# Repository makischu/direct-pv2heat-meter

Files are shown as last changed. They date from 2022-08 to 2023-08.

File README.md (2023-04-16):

# direct-pv2heat-meter

## the (initial) idea

This project is about an experimental power2heat application. Photovoltaic shall be used to heat water with a resistive heating rod. Directly off-grid, without any inverter, MPPT tracker, or the like. Note that this is known to be a dumb solution in terms of efficiency (e.g. see [1] or [2]). My goal with this project is to collect data to see how bad my solution really is. And another goal is to keep it safe.

**DANGER!** This project deals with dangerous electric power. Do not reproduce except you really know what you are doing!

As there is no regulator involved to match the characteristic of the pv panels and the heater, special care was taken to dimensioning of the parts. At the start of the project I was about to buy a hot-water heat pump, which comes with a heating rod of 1.5kW@230V (equivalents 6,52A or 35,3 Ohm). This one is not required for the intended usage, so I will use it for the project to avoid any extra plumber work. My local photovoltaic dealer offered 375W modules (datasheet names Vmpp=34,6/32,3V and Impp=10,8/8,7A which equivalents Rmpp=3,2/3,7Ohm per module).

[3] proposes a "PV magic water heater formula: Element ohms equal (Vmp/Imp) x 1.40", which translates to a recommondation of 6.8 pv modules in my case. I chose 6. 6 es even, so I can build 2 strings of 3 modules for an alternate usage. Kirchhoff allows us to double the current by simply putting 2 strings in parallel, and power goes with current squared, so I did not want to waste that option too early.

Dividing into 2 strings resulted in another advantage. The maximum input voltage reduced to 3 *41,1V *1,1=135V. This lead me to the idea of using a TL783 as a first stage of my logic power supply, as it allows 125V in-out voltage difference. Unforfunately it was not availabe at the time of ordering and I did not find a 1:1 replacement. I still wanted to power the logic by the pv itself and ensure galvanic isolation, so i designed in an extra intermediate tap in one string. So the maximum input voltage the logic has to deal with is 41,1V *1,1=45V. This is low enough to find an (available) linear regulator for 24V (for relais supply) and a DC DC converter with 3.3V output (for the logic). Furthermore this allows for direct connection to the current metering IC's breakout board SparkX Power Meter - ACS37800 (Qwiic) [4] (<60V). (not a genius idea; see drawbacks below).

See image for the first attempt's overall wiring:

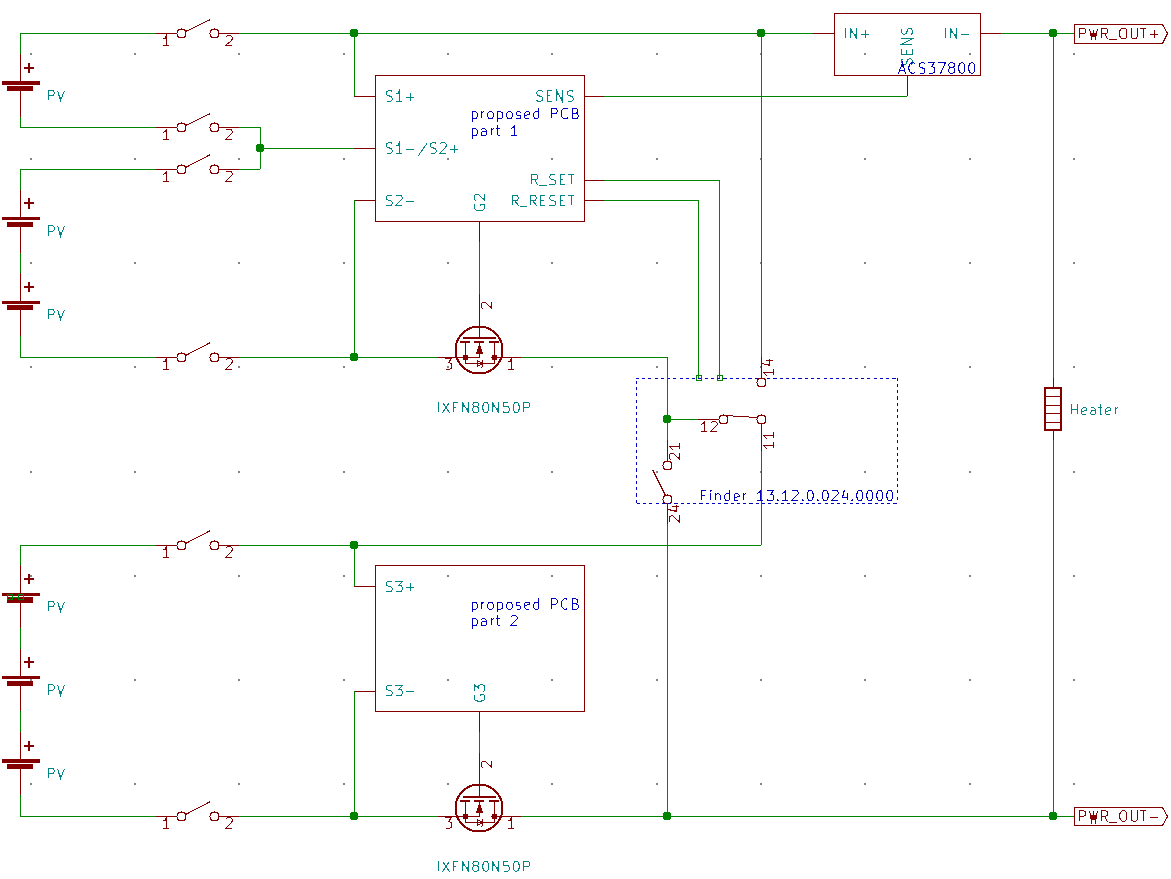
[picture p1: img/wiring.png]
Wiring


I said I want to keep the usage safe. This includes that power to the heater shall be interruptable. A certain temperature shall not be exceeded. The interruption is realized with FETs. Big ones with screw terminals (for the beginning I did not want to deal with high power on the PCB). As a temperature sensor I want to use the built-on from the hot-water heat pump. The control is not realized yet, but for the pv hardware I realized it as following: A on-command/trigger-signal has to be received every few seconds. If not, the power output will shut down. That should be safe enough for me.

The logic is realized on an ESP32, as it is well-affordable and offers BLE (read: established way of low-power galvanically isolated communication). As counterpart I built a BLE-Wifi-Bridge, also based on an ESP32 (I chose a Firebeetle, so no soldering on this part). That was enough that all the rest (logging, controlling) could be realized in software.

Although it did not work well, I leave the initially planned (and built) system overview here for reference:

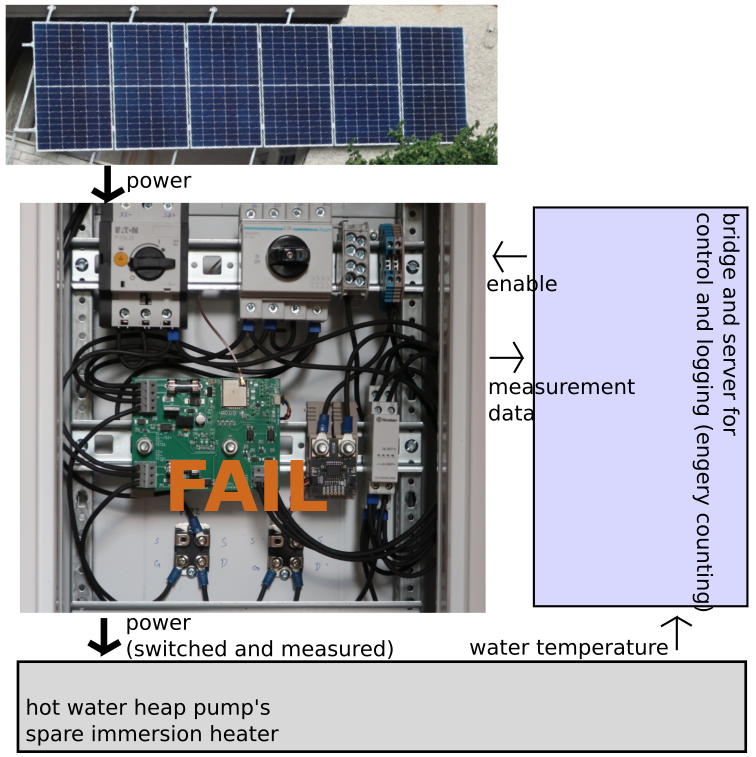
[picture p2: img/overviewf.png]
Overview


<BR/><BR/><BR/>

## the evolution

This chapter is about selected aspects of the (ongoing) development.

### Delivery Issues

Unforfunately the hot water heat pump was not delivered in time (and still isn't at the time of writing. a typical 2022 issue). So I changed the scope of heating: from water to air. Thus I avoid the delivery issue as I have a few dumb (=resisitve) 230V heaters lying around. As they have different wattages a new idea came across: Can I use different permutations to optimize efficiency? Later. First, I have to solve a different problem:

### Logic Supply Issues. Or 3 $\neq$ 1+2. Or: About pv panel mismatch.

The circuit generally works. But under certain conditions I could not turn on the load without the microcontroller going in reset, which turns the load off again by design. It turns out that the logic's supply voltage :purple_square: drops. Why? 

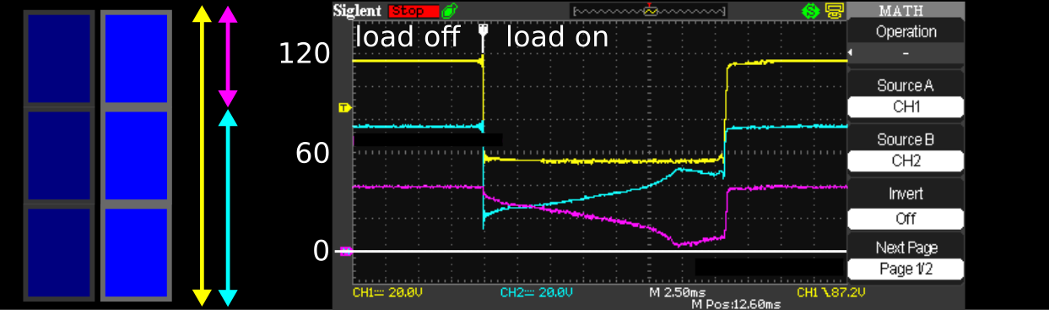
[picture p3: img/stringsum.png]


When connecting a load under low light conditions, the string voltage :yellow_square: drops, in this case from ~120 to ~60V. Then it remains stable. That is expected and should *not* cause any issues.

But I made a wrong assumption. I assumed that every panel contributes the same voltage to the string, like batteries. This is what I tried to exploit to ease my logic supply. But as I could see on the scope, the panel's voltages can diverge a lot! Almost down to zero for the panel that is supposed to support the microcontroller.

The source of this effect is mismatch. See [5] for a good introduction to the topic. In addition to inherent panel variation, we draw an extra current from one panel (to supply the logic). This current is only ~30mA (@20V). This sounds negligable in contrast to the load current (in general >1A). But it is not. Why?

Because a pv panel is not (always) a voltage source. It is known to be more like a current source. Well in my opinion it is both, but it depends on the operating point. And for operation points "far left of the MPP" a current source is definitely the better model. See plot.

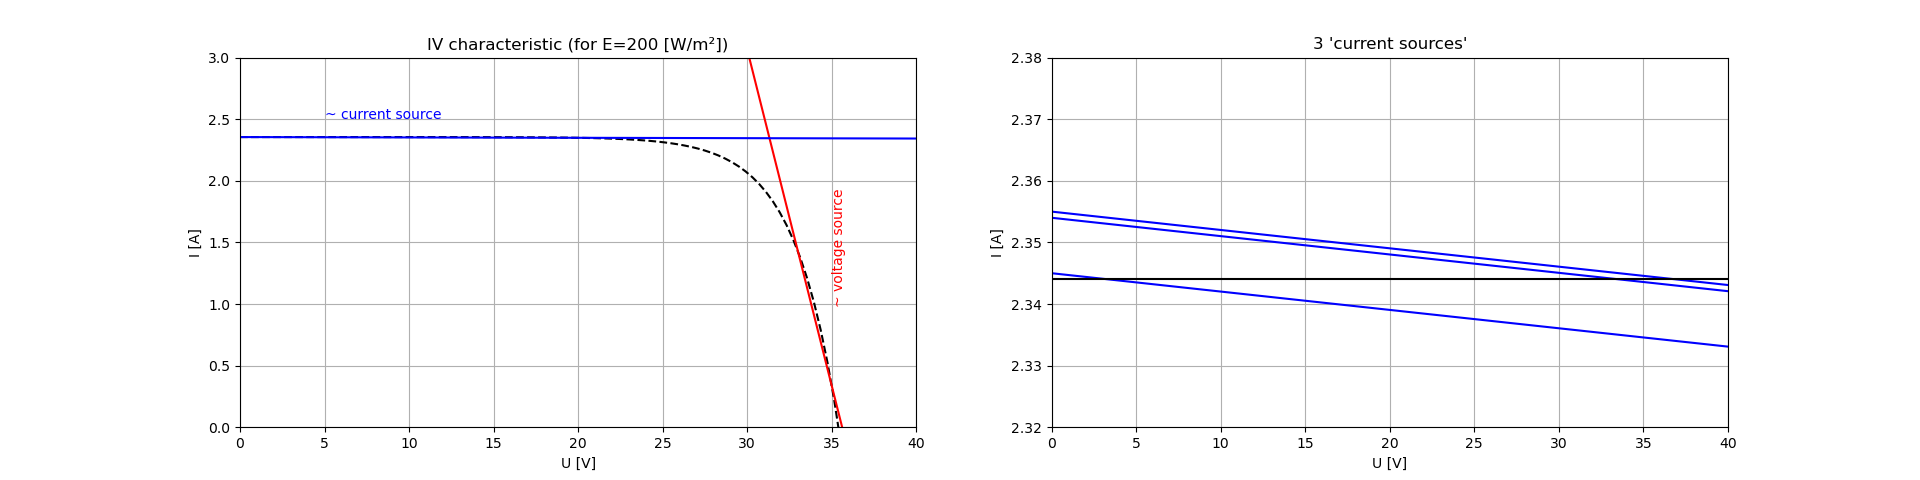
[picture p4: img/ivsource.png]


Let's zoom in to our "current source", plot it for 3 panels, assuming a little variation. As Kirchoff forces the current to be the same for all 3, voltage has to vary *a lot*. 

In the end this effect makes the initially proposed circuit fail in "current source mode", or said otherwise: it only works for high irradiation. 

A possible solution: Characterize the panels, hope that one is significantly better than all others, and hand-select the "best" one for the logic supply. Or make all others worse artifically, by a small extra load. Both approaches do not seem reasonable to me.

A more realistic solution: Generate the required votages from the whole string (3 panels instead of just 1). Unfortunately it is not soo easy to find (linear) regulators or (dc/dc) converters for that (wide) input range. Furthermore we need to consider the similar effect when switching from parallel (2x3 panels) to serial (1x6 panels) configuration. 

### Burnt FET and relay

Although overengineered in terms of voltage and current ability I managed to burn FETs. After some experimentes it was conductive regardless of gate signal. Consequently I burnt the relay, too, as it is not designed to break significant DC current at high voltage. For our purpose FETs shall either block or conduct, nothing in between, to prevent excessive power loss and thus cause its death. I assume I did not care enough about that in my first design.

So I went for a gate driver IC. Most of them offer undervoltage lockout (UVLO), but all that i have seen would suffer from oscillation in my application. UVLO disables the FET when voltage is low, thus removing the load. Removing the load leads to increasing voltage, thus enabling the FET again. For this reason I introduced a latching logic, which causes the FET to remain off in case of UVLO. 

### Server Logic

While I started with almost every logic implemented at a server in (python) software, the external components should not be stricly necessary in the long term. More work shall be done in firmware. 

[Here](theory/datasheettheory.md) I described some theory that might help with devoloping the optimization algorithm.

<BR/><BR/><BR/>

## the (preliminary) final solution

There were further issues I addressed with intermediate experiments (it's not a full diary here). In the end this resulted in a new architecture (where 1 power transistor and 1 relay is sufficient) and several small improvements (robust multi-stage power supply generation for the logic, strong fet driver with latching UVLO, also powerpath integrated on a PCB, thus avoiding external wiring, including voltage+current measurement, reducing external components, ...). 

The new architecture's power path:

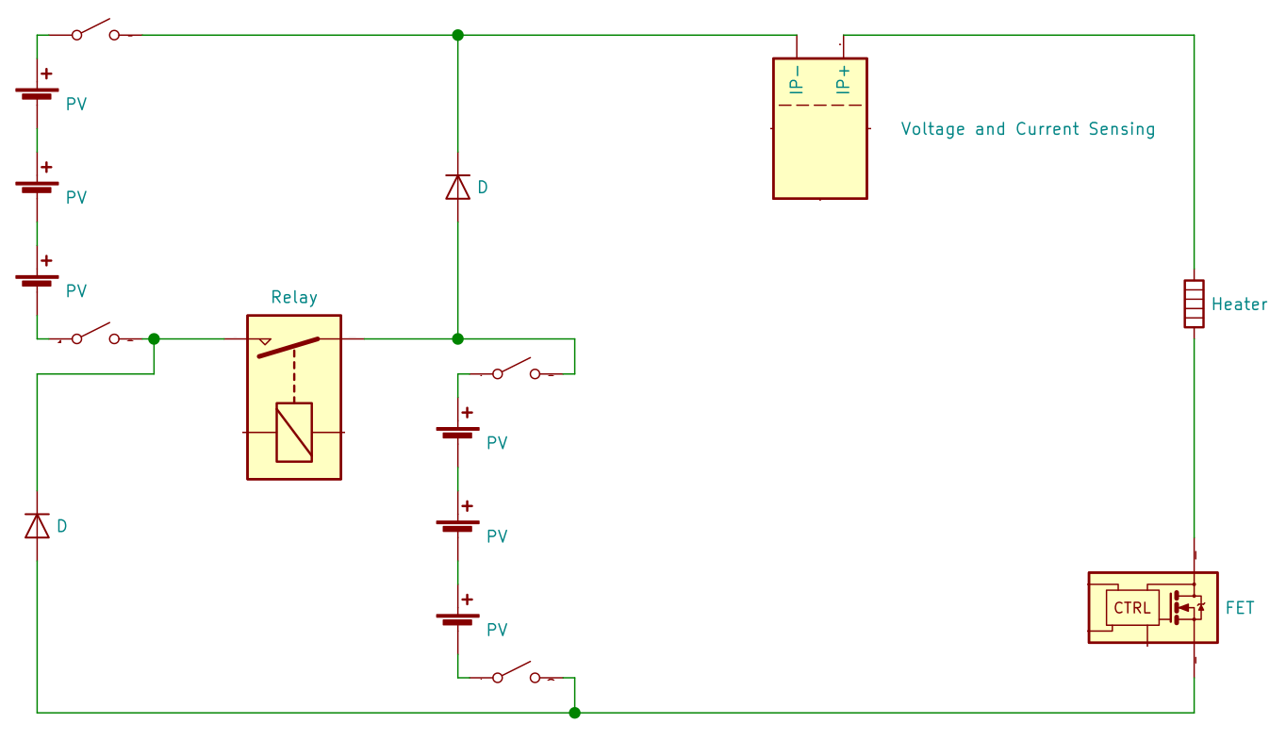
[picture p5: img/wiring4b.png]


Updated system overview:

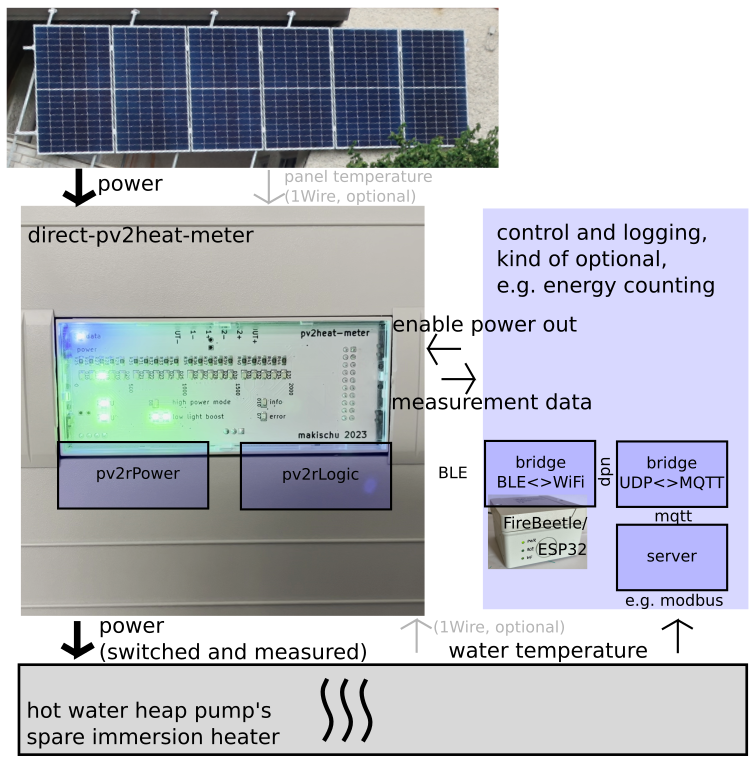
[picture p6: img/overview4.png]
Overview


Although schematics and source code are available in this repository, there is no full bill of material or building instruction. Note that the main unit consists of 2 dependent PCBs. This enabled sequential development and stacking in a din rail housing (an apra rail DB 6).  Here is an impression of the result:

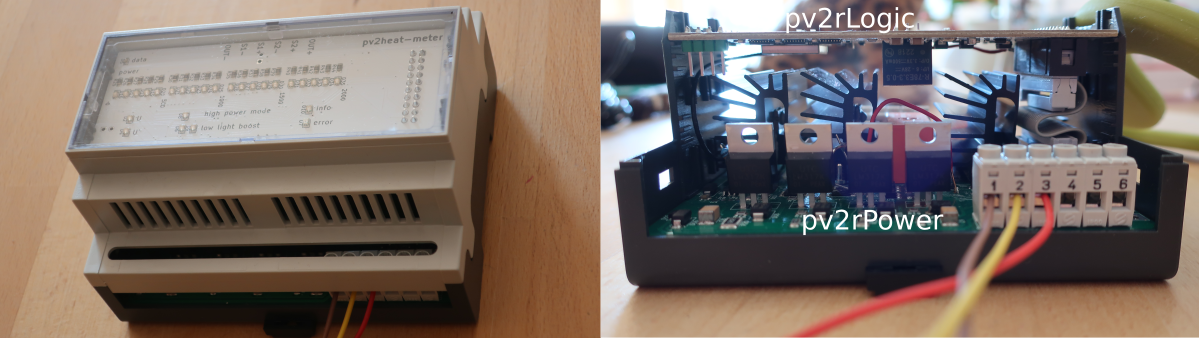
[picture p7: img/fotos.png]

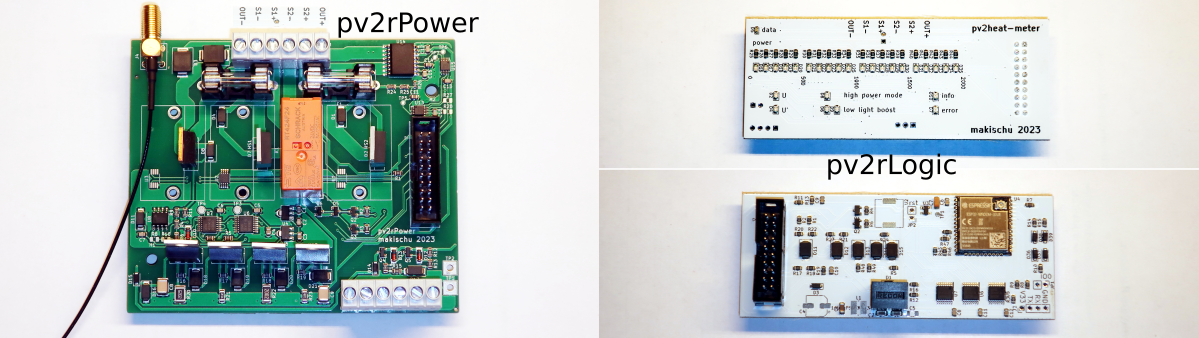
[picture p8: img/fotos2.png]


In contrast to the first attempts, the number of wires is greatly reduced. Only 6 power wires are required: 2x2 for the pv input and 2 for the power output (top). I spent another 6 logic ports (bottom), for 1Wire temperature sensor(s) and DigitalIO (not isolated).

## known issues

This is (just) a proof of concept. It works! Hopefully you can extract some ideas. But I do not recommend exact copying, at least not without having read the known issues (which I solved manually for my device but schematics still contain the errors):
- pv2rPower UVLO latch has S and R interchanged. 
- pv2rPower GATE_LOGIC_VCC exceeds 3.3V, as regulator requires minimum load.
- pv2rPower GATE_DRV_OUT level conversion may fail; it limits to ~2V rather than 3.3V.
- pv2rPower LM317s are getting hot. Current consumption should be optimized. Or cooling.
- pv2rLogic L1 was missing in data. I replaced by wire.
- pv2rLogic U2 has wrong footprint. Left not-placed as is not required.
- pv2rLogic 1Wire sometimes fails. Works well with smaller pullup.
- although the pv2heat-meter itself is designed for grid-independence, the server components currently run from grid.
- logic supports my circumstances, may need adaption for your needs (e.g. you could omit the server component and build a truely independent standalone device)
- the optimization algorithm itself is also just a prototype, hardcoded for my (panel) parameters. 
- ...

<BR/>
<BR/>

[1] https://www.solarpaneltalk.com/forum/solar/solar-energy-facts/325254-solar-panel-directly-connected-to-immersion-heater <BR/>
[2] https://diysolarforum.com/threads/direct-solar-pv-water-heater.27937/ <BR/>
[3] http://waterheatertimer.org/Solar-power-curves-for-water-heater.html <BR/>
[4] https://www.sparkfun.com/products/17873 <BR/>
[5] https://www.pveducation.org/pvcdrom/modules-and-arrays/mismatch-for-cells-connected-in-series and https://www.pveducation.org/node/168/talk <BR/>

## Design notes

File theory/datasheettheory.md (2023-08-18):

For this project I needed a (temperaturedependent) description of the IV-curve of my photovoltaic module. So I developed one, based on the datasheet and a litte math.

The model is as simple as:
$$I(U) = I_L - I_0 \cdot \exp(b\cdot U)$$

3 unknown coefficients tell us that 3 equations might be useful to determine them. Luckily the datasheet tells us 3 different working points, so we can request:

$$ I_{SC}=I_L-I_0\cdot 1 $$

$$ 0=I_L-I_0\cdot \exp(b\cdot U_{OC}) $$

$$ I_{mpp}=I_L-I_0\cdot \exp(b\cdot U_{mpp}) $$

where $I_{SC}$ is the short-circuit current, $U_{OC}$ is the open circuit voltage, $I_{mpp}$ and $U_{mpp}$ are maximum power point values. 

Unfortunately, temperature coefficients are only given for $I_{SC}$, $U_{OC}$, and $P_{mpp}(=I_{mpp}\cdot U_{mpp})$ (grr... the product, not the factors...). Ok, let's replace $I_{mpp}=P_{mpp}/U_{mpp}$:

$$  \frac{P_{mpp}}{U_{mpp}}=I_L-I_0\cdot \exp(b\cdot U_{mpp}) $$

As $U_{mpp}$ is not given, there are now 4 unknowns, so a 4th condition might be useful. Luckily there is one. We know that the power P has a maximum at the MPP, so we can state a derivation of zero:

$$\frac{d}{dU}P(U_{mpp}) \stackrel{!}{=} 0 $$

$$\frac{d}{dU}P = \frac{d}{dU}(U\cdot I(U)) = 
\frac{d}{dU}U\cdot I(U) + U\cdot \frac{d}{dU}(I(U)) =
1\cdot I(U) + U\cdot \frac{d}{dU}I(U)  $$

intermediate calcualtion:

$$\frac{d}{dU}I(U) = \frac{d}{dU}I_L - \frac{d}{dU}I_0 \cdot \exp(b\cdot U) - I_0 \cdot \exp(b\cdot U) \cdot b$$

inserted in the above:

$$\frac{d}{dU}P = 1 \cdot I(U) + U\cdot (\frac{d}{dU}I_L - \frac{d}{dU}I_0 \cdot \exp(b\cdot U) - I_0 \cdot \exp(b\cdot U) \cdot b)$$

$$\frac{d}{dU}P = \frac{P}{U} + U\cdot \frac{d}{dU}I_L + U \cdot \exp(b\cdot U) \cdot ( -\frac{d}{dU}I_0  - I_0  \cdot b)$$

$$0 \stackrel{!}{=}  \frac{P_{mpp}}{U_{mpp}} + U_{mpp}\cdot dI_L + U_{mpp} \cdot \exp(b\cdot U_{mpp}) \cdot ( -dI_0  - I_0  \cdot b)$$

Looks like we won more variables, $dI_L$ and $dI_0$, but we can assume voltage-independency, $\approx0$:
$$0 \stackrel{!}{=}  \frac{P_{mpp}}{U_{mpp}} - U_{mpp} \cdot \exp(b\cdot U_{mpp}) \cdot  I_0  \cdot b$$

With this as the 4th condition, we can fit the parameters, including their temperature-dependency. 

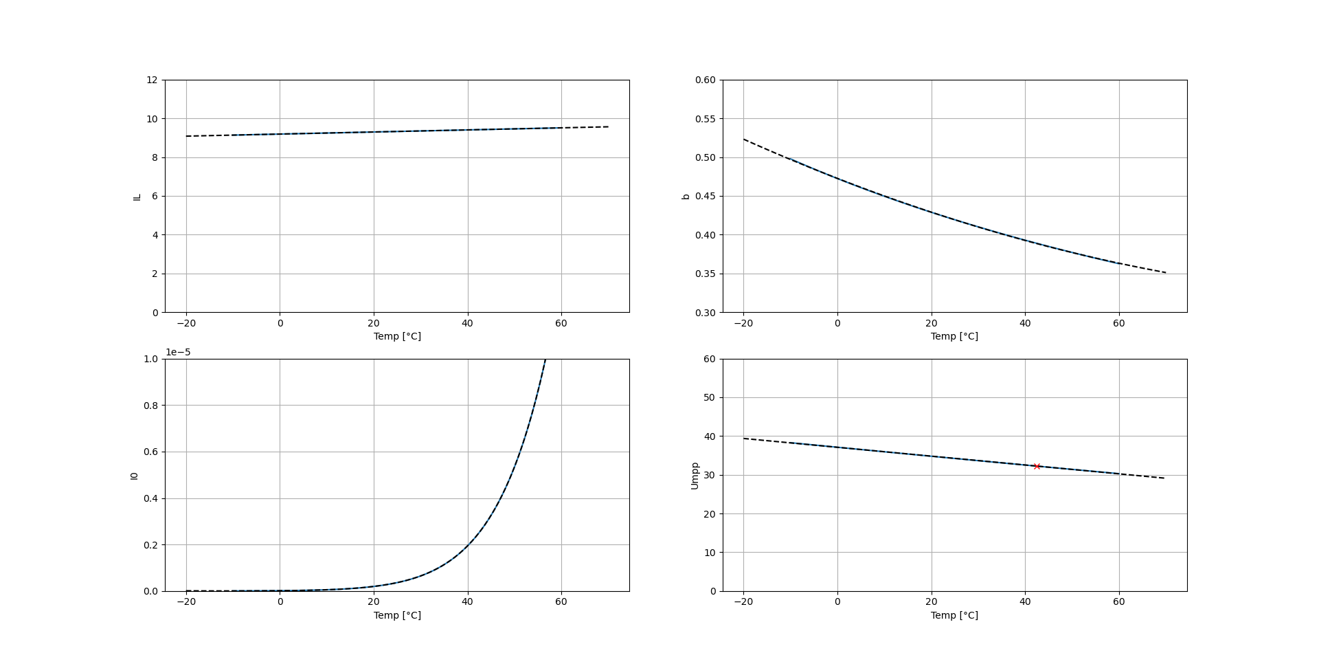
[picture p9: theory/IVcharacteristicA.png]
IVcharacteristicA


Given the parameters, we can draw curves for every temperature we like.

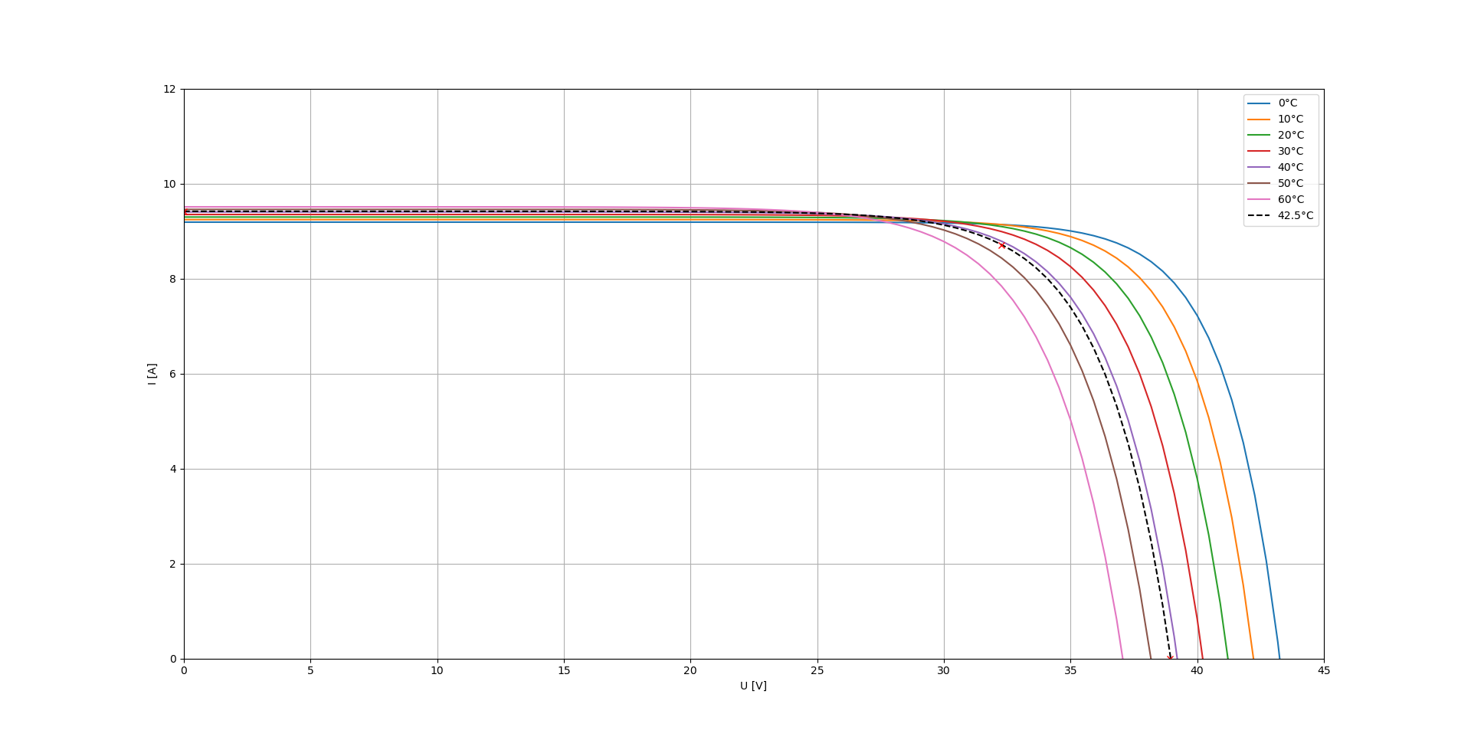
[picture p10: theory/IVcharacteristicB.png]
IVcharacteristicB


What is still missing is the irradiation dependency. Here we simply assume $I_L$ to be directly proportional to the irradition power $E$, which leads to the final model, $T$ is temperature in °C:

$$I_{L,800}(T) = 0.00536952652515192\cdot T + 9.191799383372592 $$

 $$ I_0(T) = 1.87942600e^{-20}\cdot T^8
-4.86961403e^{-19}\cdot T^7
+1.17433360e^{-16}\cdot T^6 \\
+2.68834696e^{-15}\cdot T^5 
+1.81678067e^{-13}\cdot T^4
+5.95891947e^{-12}\cdot T^3 \\
+1.31406079e^{-10}\cdot T^2
+1.85584490e^{-09}\cdot T
+1.21572220e^{-08}
$$

$$ b(T)  = 8.84231653091366e^{-06}\cdot T^2 -0.002355382115251495\cdot T + 0.4725462916388404$$

$$ I(T,E,U)  = \frac{E}{800}\cdot I_{L,800}(T) - I_0(T)\cdot \exp(b(T)\cdot U)$$

Let's countercheck that with the second datapoint given from the datasheet, $E[W/m²]=1000$ at $25\text{°C}$.

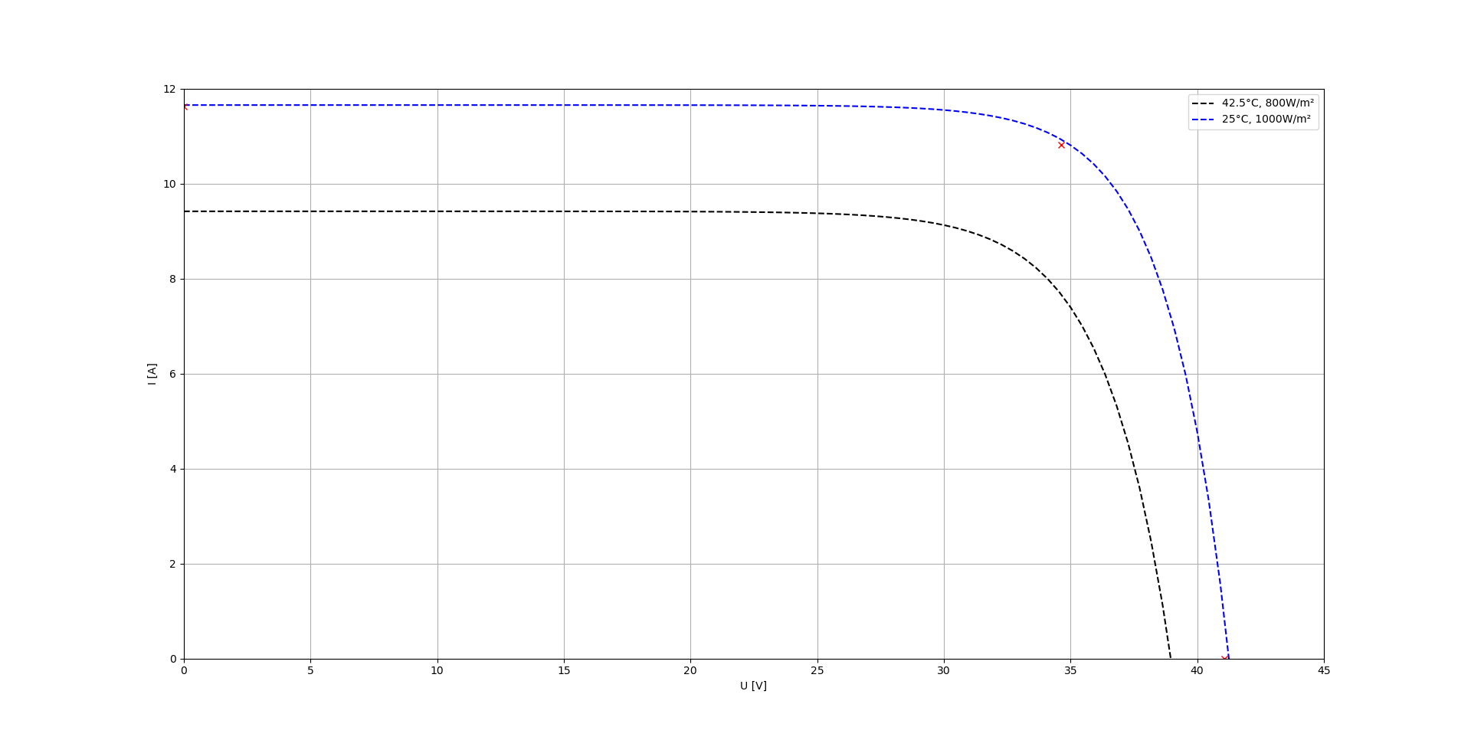
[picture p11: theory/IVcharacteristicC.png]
IVcharacteristicC


I am happy with that. I think the error should be negligable in relation to the impact of several other effects which are not modelled here at all.

Note that in general we don't know temperature nor irradiation. In my case I spent a temperature sensor right under one of the modules. I am aware that this will not deliver the silicon temperature, but it should be a good estimate. As I also can measure $I$ und $U$, I should be able to estimate $E$. To be checked.

Knowing the IV curve allows me to estimate the power at a different working point (series vs. parallel wiring), to see if it is worth switching. Quite a lot of calculation to be done for deciding between only two options ;)

Here is an illustration of what I mean. We can choose between the crossing of the black line with the either red or blue. Which one is better (in terms of: delivers more power) depends on the situation (mainly the light).

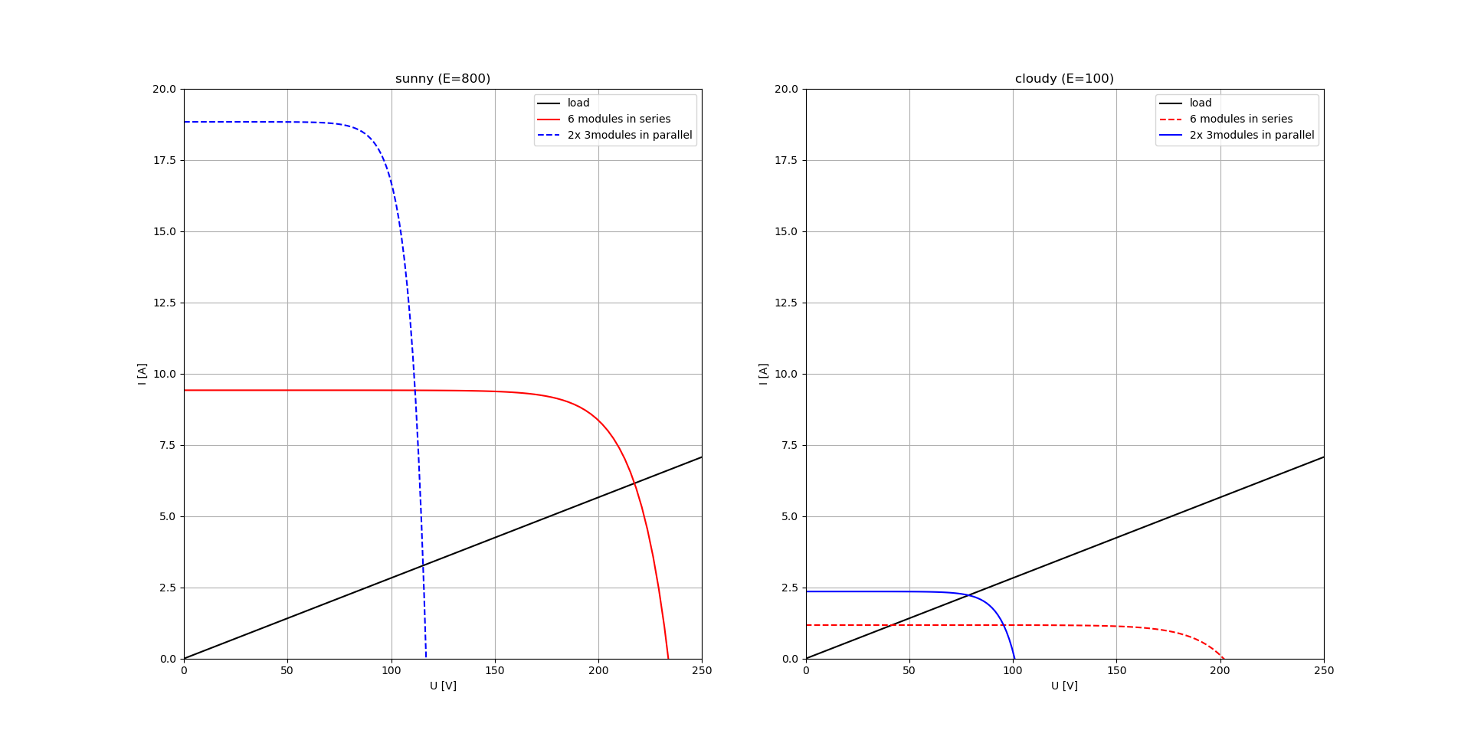
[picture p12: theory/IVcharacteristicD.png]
IVcharacteristicD


Some words on efficiency. When I started with this project I often found threads claiming that such a solution is bad in terms of efficiency. Let's do own estimates based on what we have learned so far (here for 30°C):

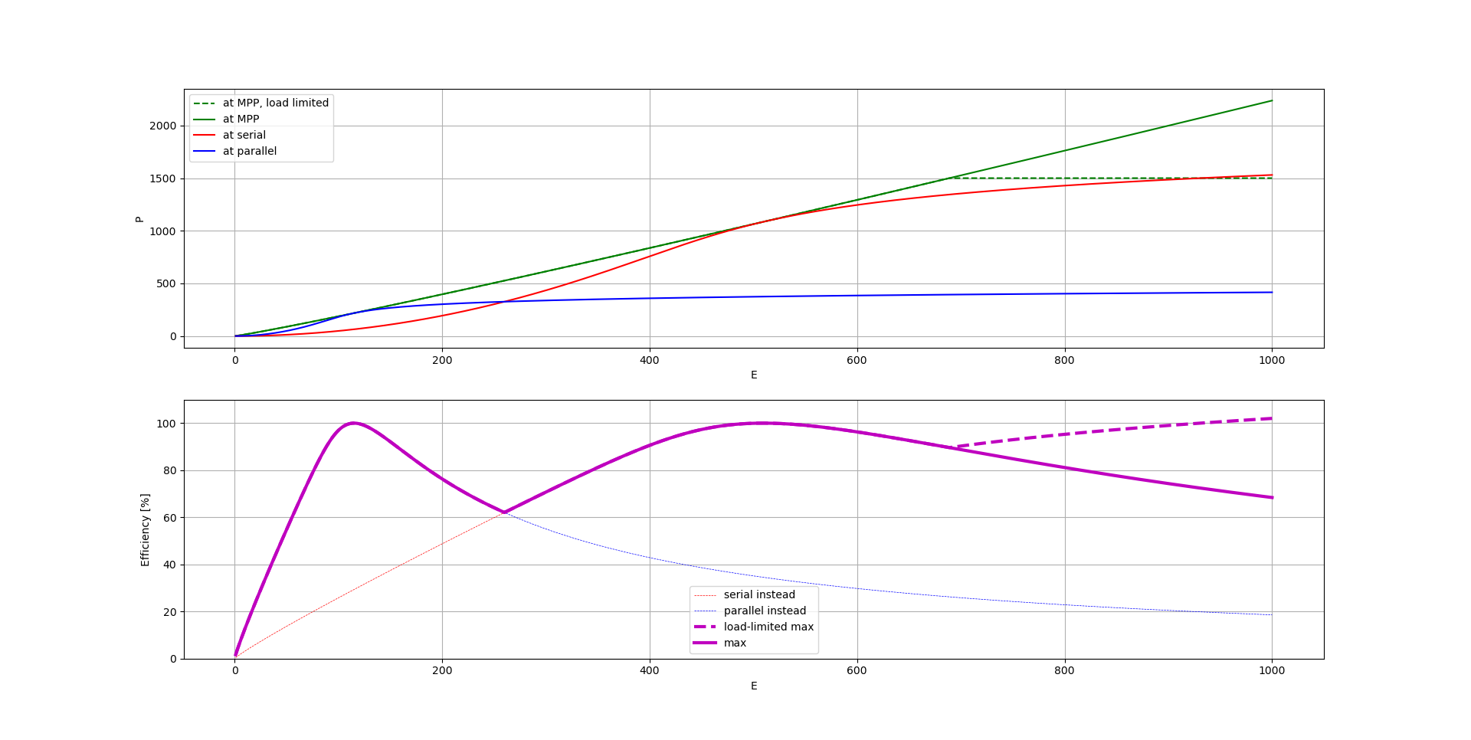
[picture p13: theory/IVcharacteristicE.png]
IVcharacteristicE


This theory sais we can achieve more than 60% efficiency for a wide range of irradition, often much better. I don't think this is too bad, if you consider the simplicity of the circuitry. 

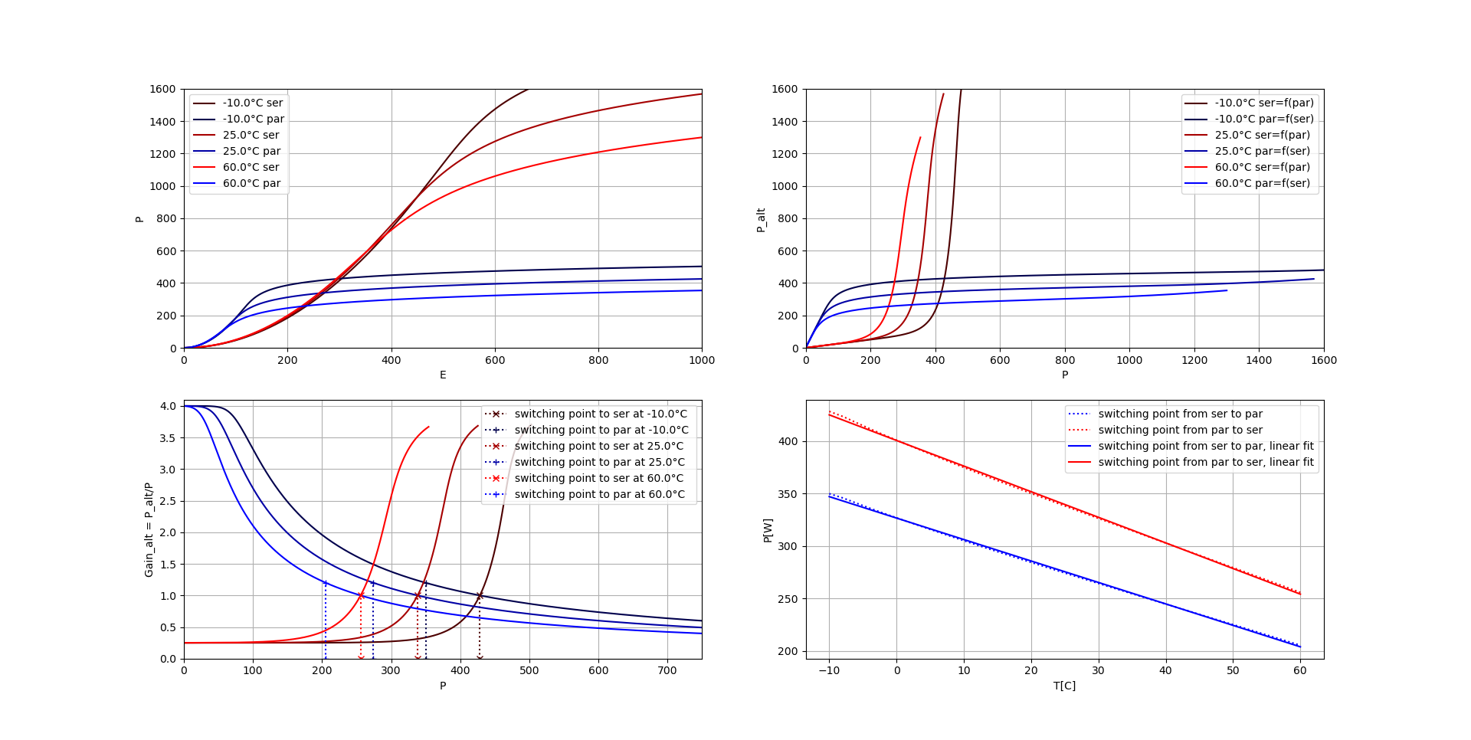
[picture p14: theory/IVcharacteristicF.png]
IVcharacteristicF


Finally, I used these insights to simplify the decision for the microcontroller, when to switch from parallel to serial configuration and vise versa. Note that this solution is only valid for my panels, my load, and all the other assumptions made on this page. In this case the only remaining variable is temperature, and the decision is reduced to a comparison of (measured) power with a (temperaturedependent) threshold. This avoids the need for heavier math on the microcontroller (which in my case does not even offer a double precision unit...).

Note that I chose to switch to serial configuration early, because of the high rise in gain for this direction, to reduce the effect of unideal models and measurement errors. As you can see in the left upper plot, the power in parallel configuration is almost constant from 200 to 1000 W/m2, while for serial configuration the power greatly increases. The leads to a great uncertainty when estimating [E and from that] the serial power from the parallel power. False not-switching to serial mode wastes a lot of power and efficiency, so this is the case we want to avoid.

In contrast, I chose to switch to parallel configuration late, at more than 20% expected gain, because there is little to gain in absolute values and this way there is kind of an intrinsic hysteresis. 

Instead of P we can express the condition also for U and I (from P=U*I and R=U/I). Due to the assumed constant ohmic load, the conditions are equivalent. And one of them is sufficient. So we can omit the current measurement and just use voltage U (and temperature) as input for the switching logic.

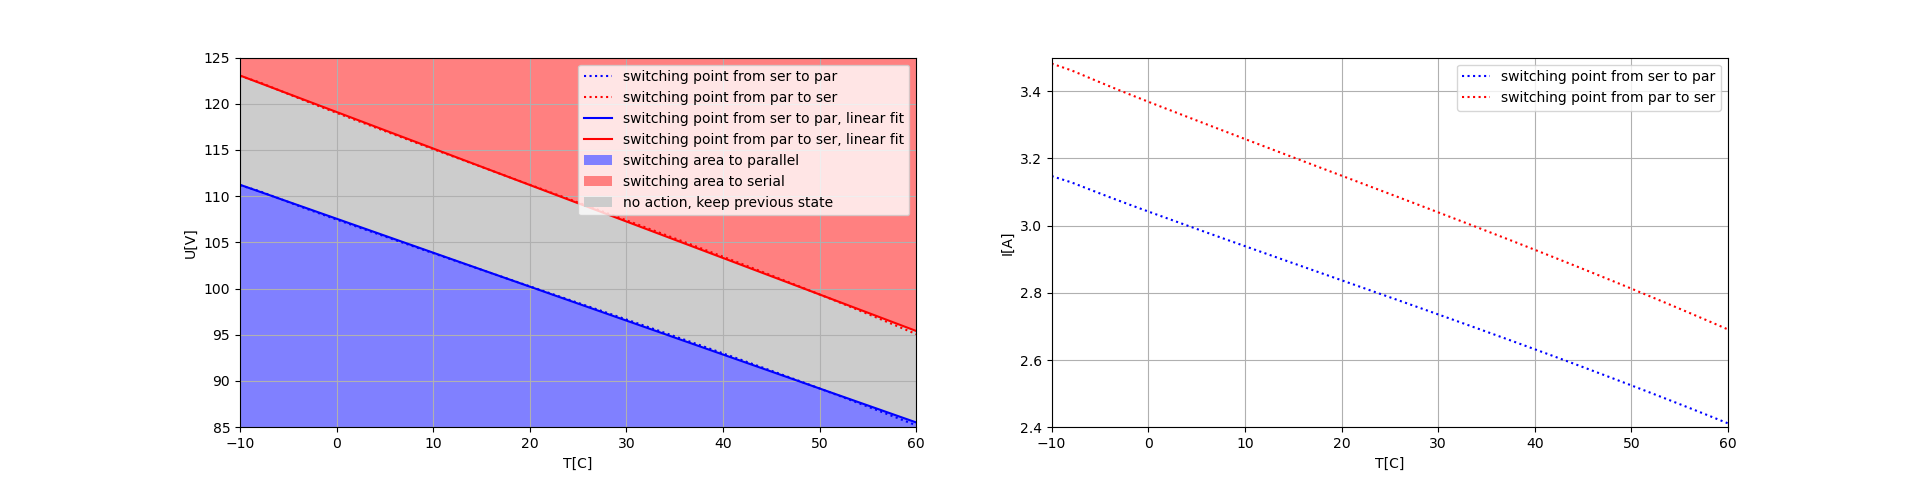
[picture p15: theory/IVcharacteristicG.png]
IVcharacteristicG


Summary: Despite the longish derivation, the result is quite simple. Only (1) voltage and temperature measurement are required to feed a simple microcontroller-suitable decision logic, capable to choose between parallel and serial configuration in order to optimise power output for a given situation/hardware.

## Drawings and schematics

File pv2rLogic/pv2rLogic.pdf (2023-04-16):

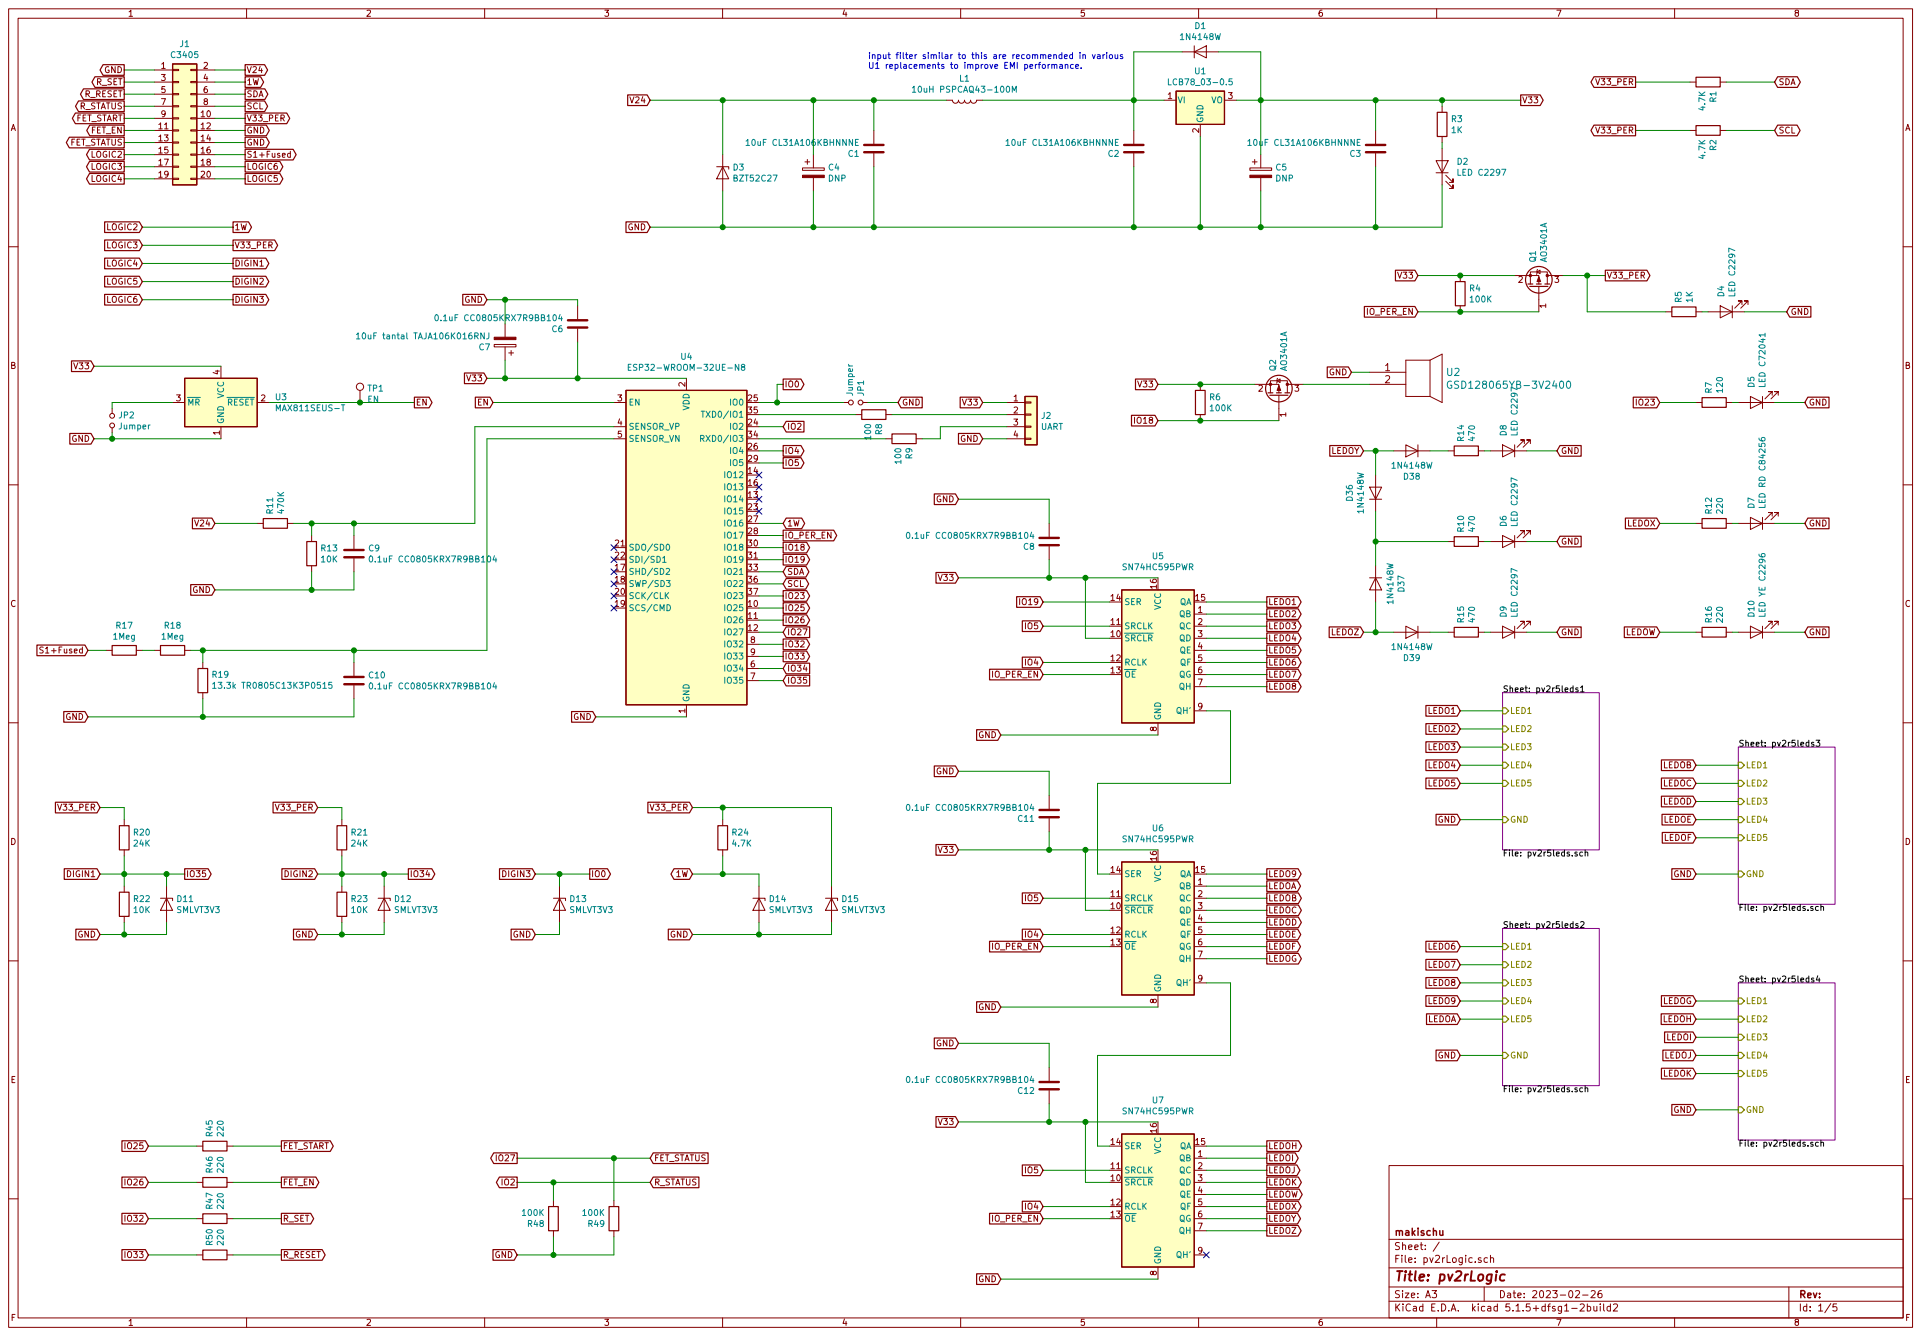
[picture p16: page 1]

input filter similar to this are recommended in various
U1 replacements to improve EMI performance.

2 SCK/CLK 20 SDO/SD0 21 SDI/SD1 22

File: pv2rLogic.sch Sheet: / makischu

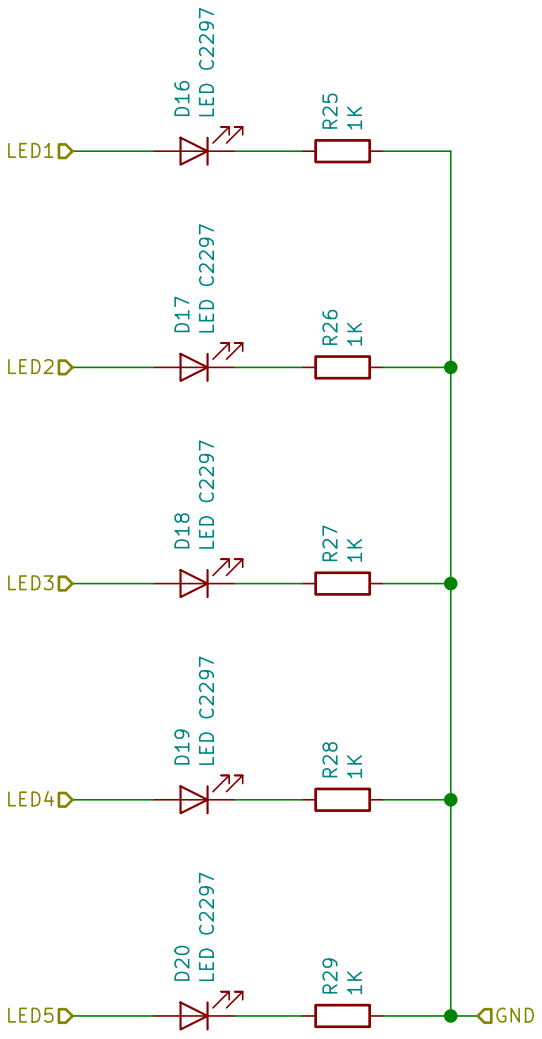
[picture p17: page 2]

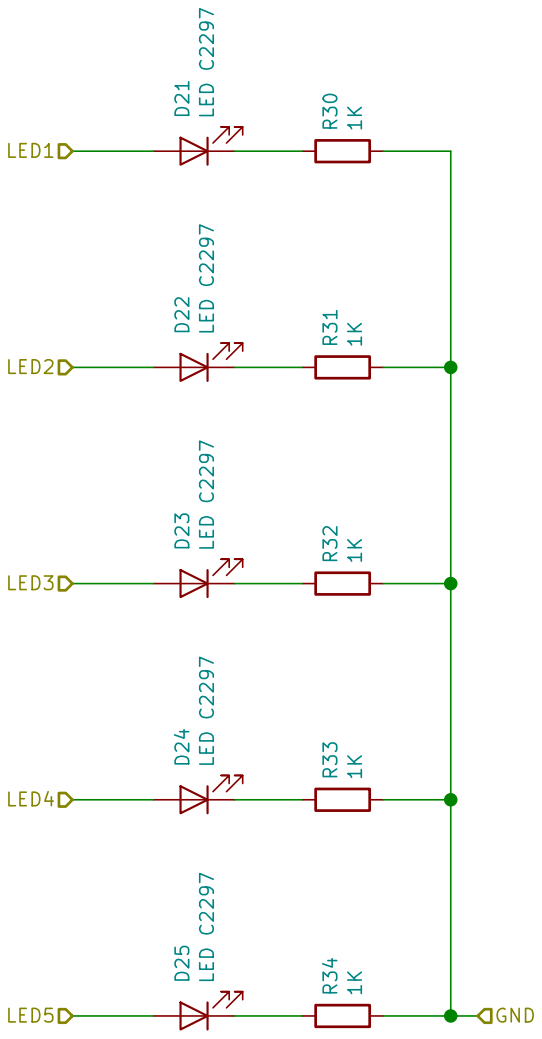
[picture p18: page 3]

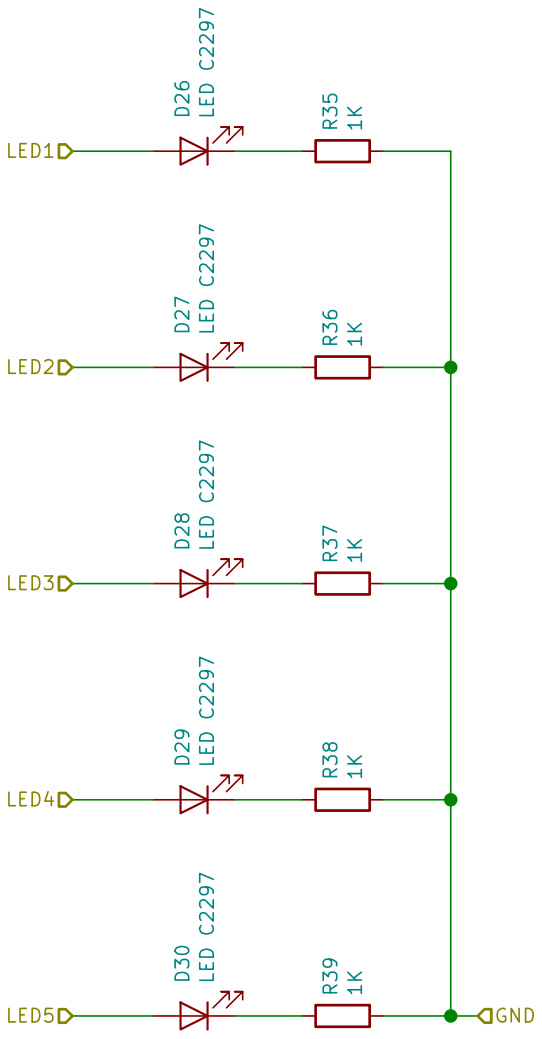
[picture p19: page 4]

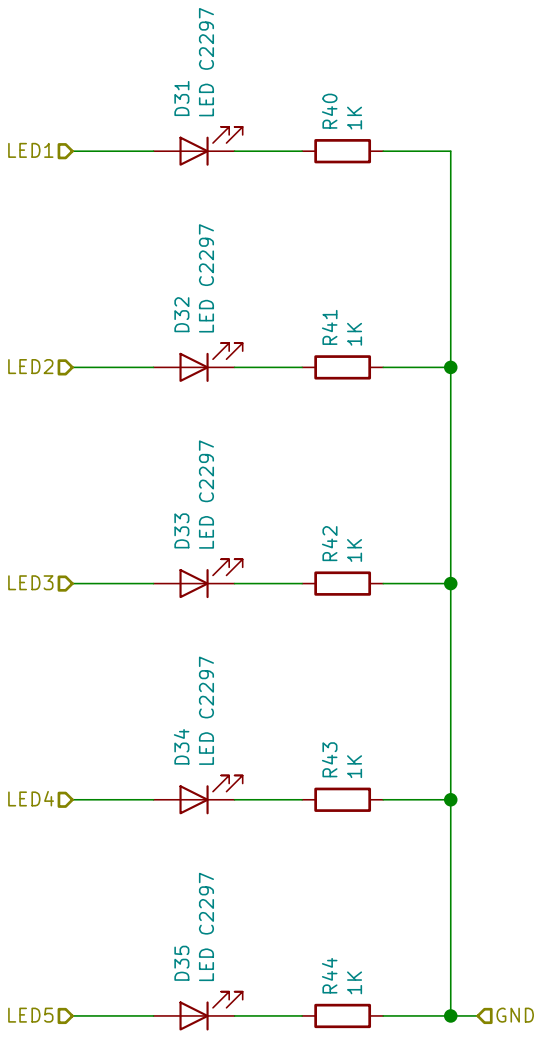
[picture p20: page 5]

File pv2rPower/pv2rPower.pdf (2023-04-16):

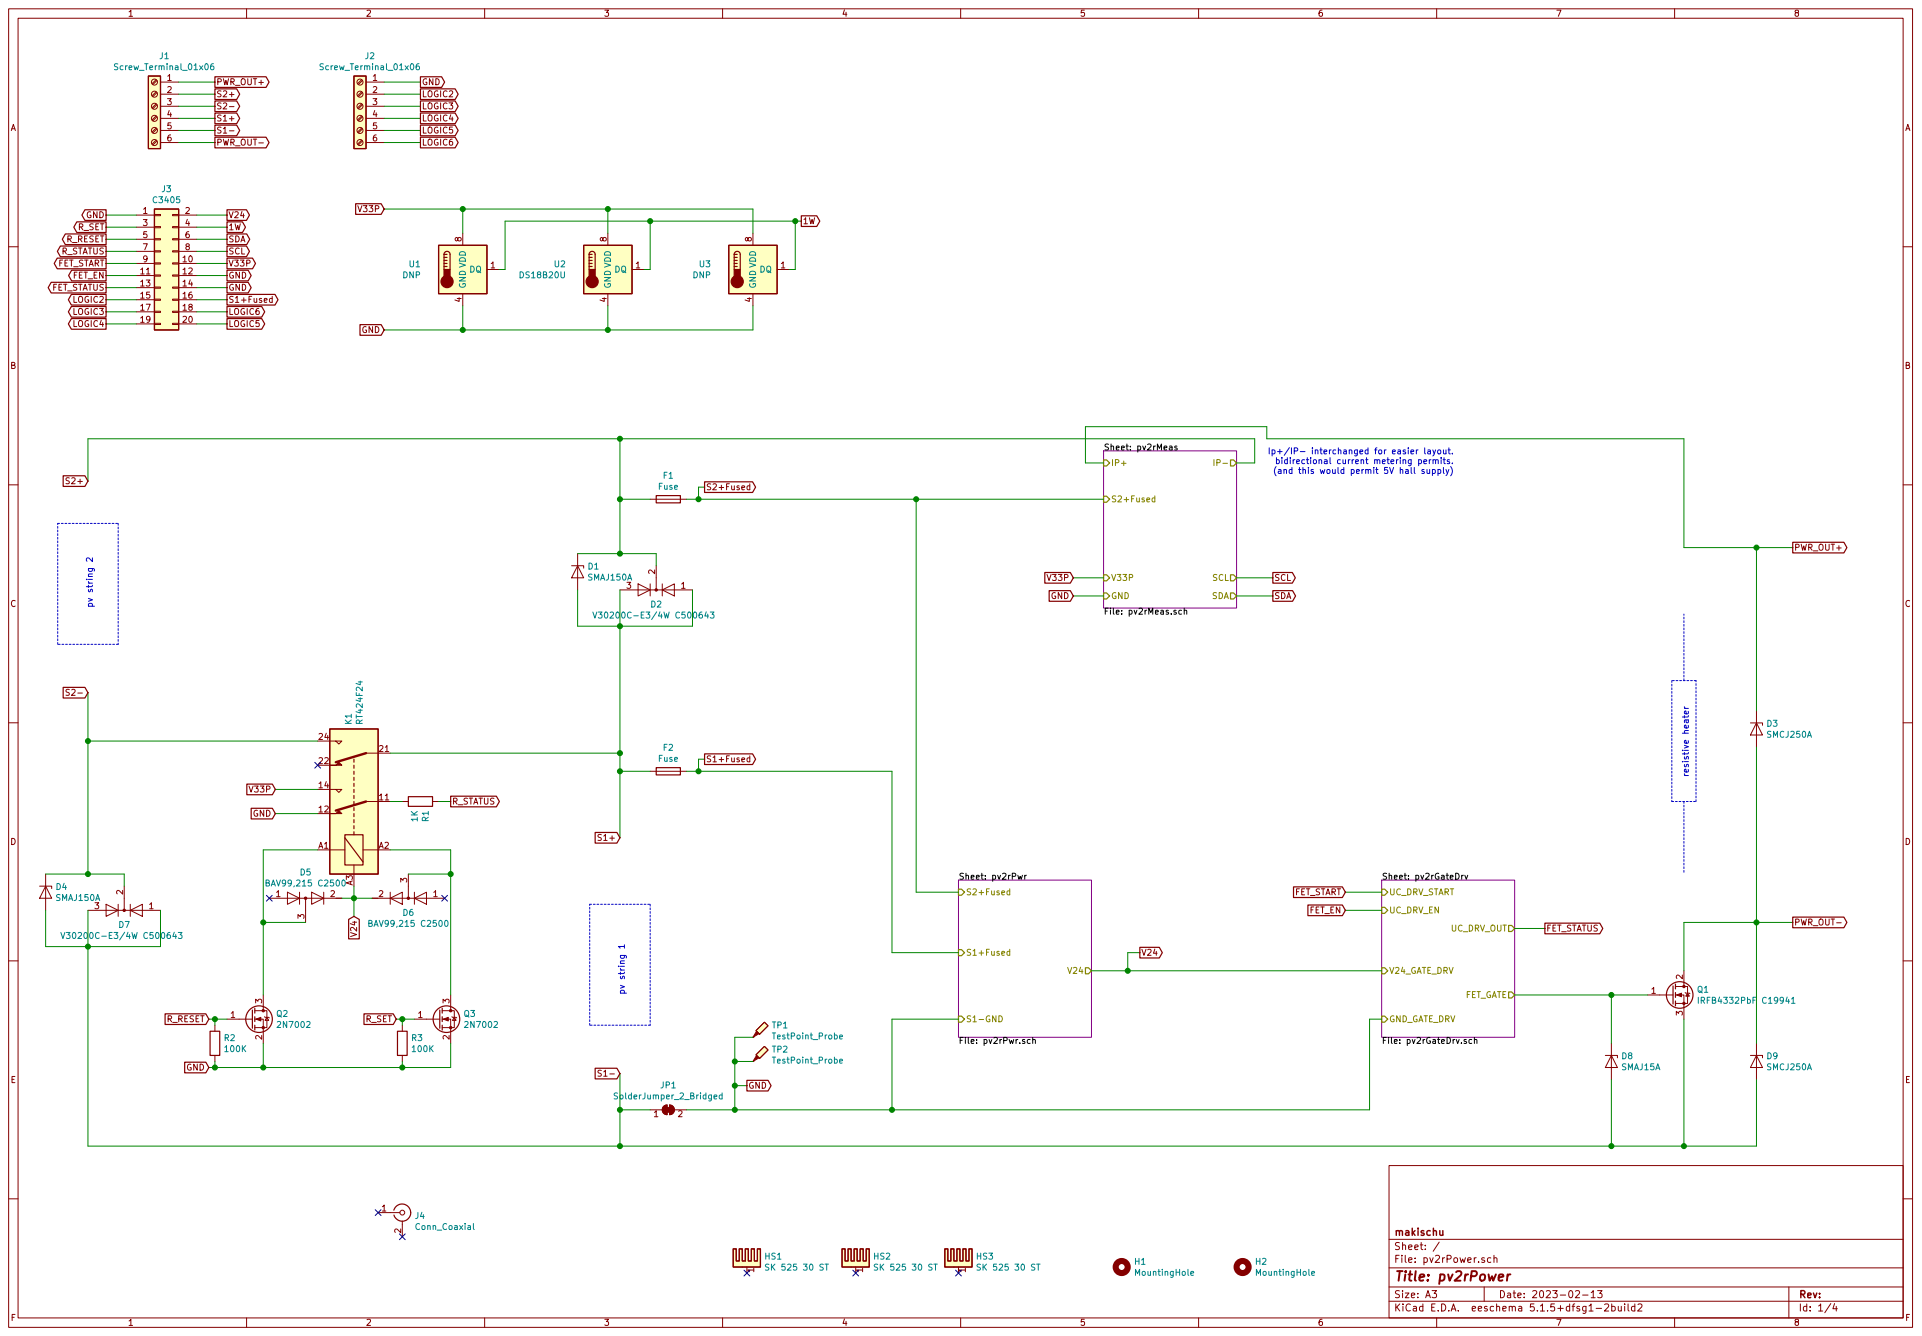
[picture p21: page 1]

Ip+/IP- interchanged for easier layout.
bidirectional current metering permits.
(and this would permit 5V hall supply)

File: pv2rMeas.sch S2+Fused GND

Sheet: pv2rPwr
File: pv2rPwr.sch S2+Fused S1-GND

File: pv2rPower.sch Sheet: / makischu

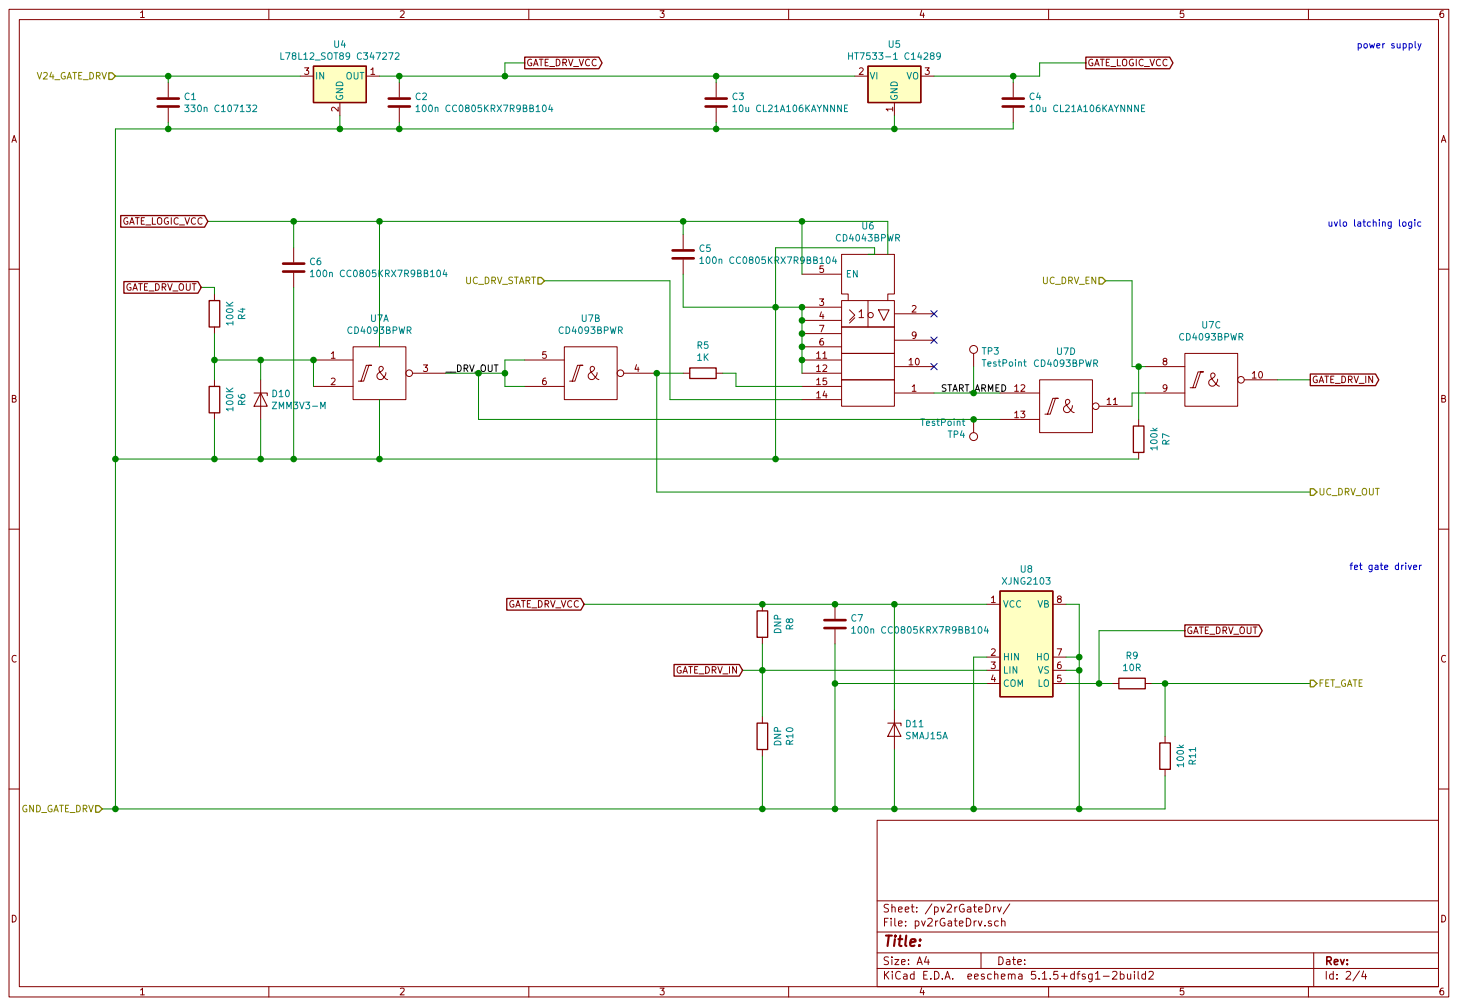
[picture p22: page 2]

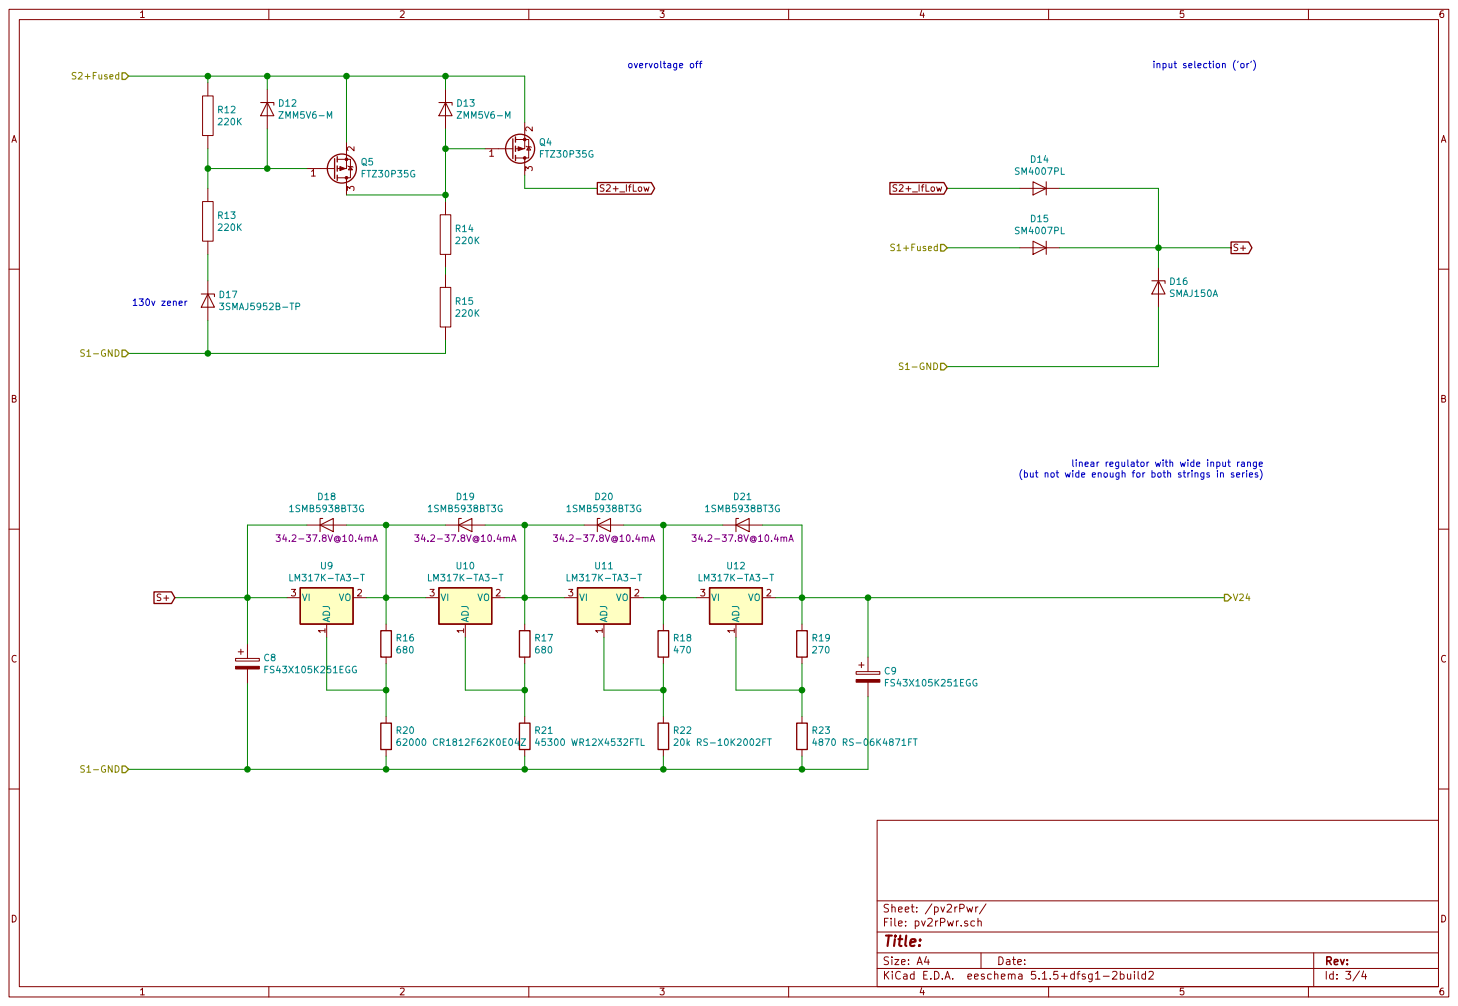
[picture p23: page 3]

(but not wide enough for both strings in series) 130v zener

linear regulator with wide input range

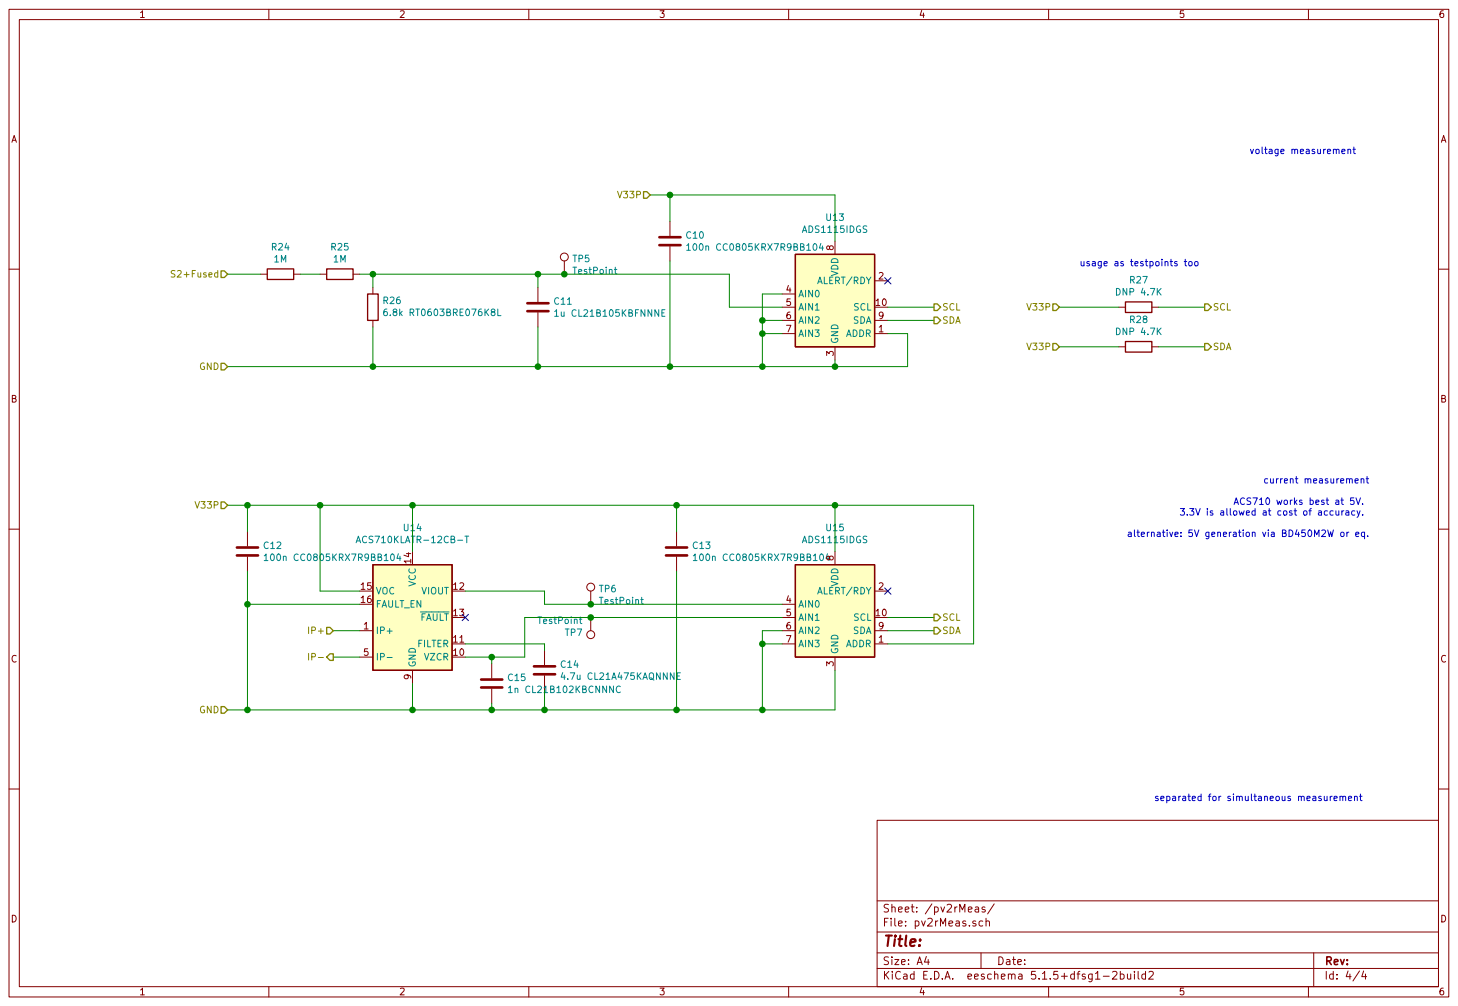
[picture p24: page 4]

usage as testpoints too

separated for simultaneous measurement current measurement ACS710 works best at 5V. 3.3V is allowed at cost of accuracy.

9 U14 ACS710KLATR-12CB-T ADDR 1 SCL 10 ALERT/RDY 2 GND

alternative: 5V generation via BD450M2W or eq.

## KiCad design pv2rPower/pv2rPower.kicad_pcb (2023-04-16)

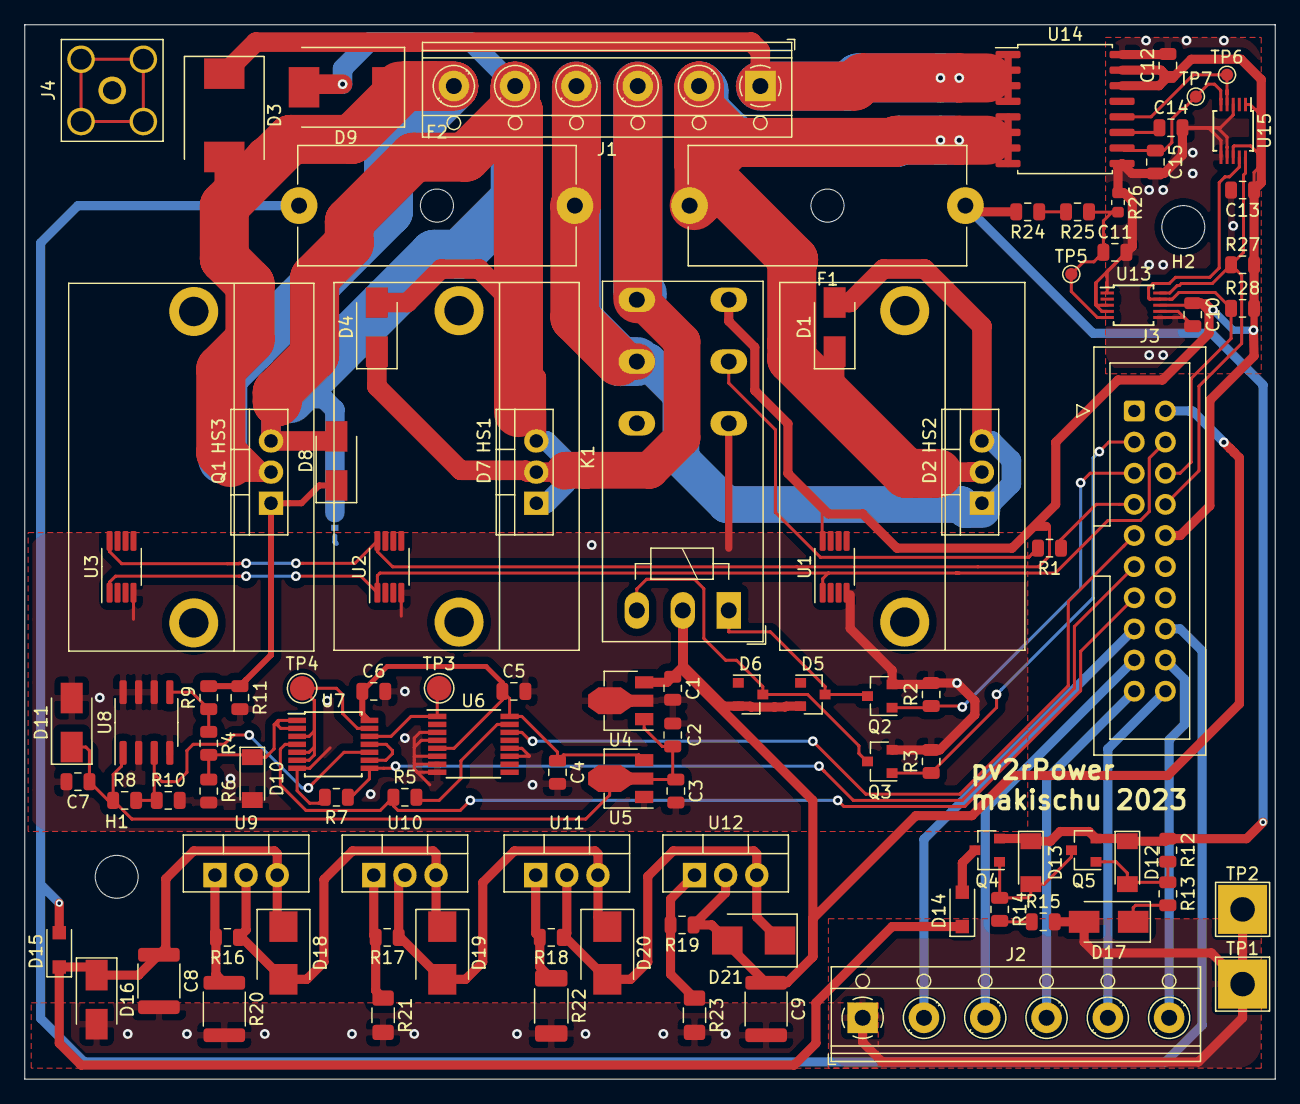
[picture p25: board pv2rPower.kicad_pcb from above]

Board: 2 copper layers, 102.0 x 86.0 mm, 104 parts (1 on the bottom side), 56 nets.

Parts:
C1: 330n C107132; C_0805_2012Metric
C2, C5, C6, C7, C10, C12, C13: 100n CC0805KRX7R9BB104; C_0805_2012Metric
C3, C4: 10u CL21A106KAYNNNE; C_0805_2012Metric
C8, C9: FS43X105K251EGG; C_1812_4532Metric
C11: 1u CL21B105KBFNNNE; C_0805_2012Metric
C14: 4.7u CL21A475KAQNNNE; C_0805_2012Metric
C15: 1n CL21B102KBCNNNC; C_0805_2012Metric
D1, D4, D16: SMAJ150A; D_SMA
D2, D7: V30200C-E3/4W C500643; TO-220-3_Vertical
D3, D9: SMCJ250A; D_SMC
D5, D6: BAV99,215 C2500; SOT-23
D8, D11: SMAJ15A; D_SMA
D10: ZMM3V3-M; D_MiniMELF
D12, D13: ZMM5V6-M; D_MiniMELF
D14, D15: SM4007PL; D_SOD-123F
D17: 3SMAJ5952B-TP; D_SMA
D18, D19, D20, D21: 1SMB5938BT3G; D_SMB
F1, F2: Fuse; Fuseholder_Cylinder-5x20mm_Schurter_0031_8201_Horizontal_Op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
H1, H2: MountingHole; MountingHole_3.5mm
HS1, HS2, HS3: SK 525 30 ST; Heatsink_Fischer_SK525_30_ST_TO220_2xDrill2.5mm
J1, J2: Screw_Terminal_01x06; TerminalBlock_RND_205-00016_1x06_P5.00mm_Horizontal
J3: C3405; IDC-Header_2x10_P2.54mm_Vertical
J4: Conn_Coaxial; SMA_Amphenol_132203-12_Horizontal
JP1: SolderJumper_2_Bridged; SolderJumper-2_P1.3mm_Bridged_RoundedPad1.0x1.5mm
K1: RT424F24; Relay_DPDT_Schrack-RT2-FormC-Dual-Coil_RM5mm
Q1: IRFB4332PbF C19941; TO-220-3_Vertical
Q2, Q3: 2N7002; SOT-23
Q4, Q5: FTZ30P35G; SOT-23
R1, R5: 1K; R_0805_2012Metric
R2, R3, R4, R6: 100K; R_0805_2012Metric
R7, R11: 100k; R_0805_2012Metric
R8, R10: DNP; R_0805_2012Metric
R9: 10R; R_0805_2012Metric
R12, R13, R14, R15: 220K; R_0805_2012Metric
R16, R17: 680; R_0805_2012Metric
R18: 470; R_0805_2012Metric
R19: 270; R_0805_2012Metric
R20: 62000 CR1812F62K0E04Z; R_1812_4532Metric
R21: 45300 WR12X4532FTL; R_1206_3216Metric
R22: 20k RS-10K2002FT; R_2010_5025Metric
R23: 4870 RS-06K4871FT; R_1206_3216Metric
R24, R25: 1M; R_0805_2012Metric
R26: 6.8k RT0603BRE076K8L; R_0603_1608Metric
R27, R28: DNP 4.7K; R_0805_2012Metric
TP1, TP2: TestPoint_Probe; TestPoint_THTPad_4.0x4.0mm_Drill2.0mm
TP3, TP4: TestPoint; TestPoint_Pad_D2.0mm
TP5, TP6, TP7: TestPoint; TestPoint_Pad_D1.0mm
U1, U3: DNP; MSOP-8_3x3mm_P0.65mm
U2: DS18B20U; MSOP-8_3x3mm_P0.65mm
U4: L78L12_SOT89 C347272; SOT-89-3
U5: HT7533-1 C14289; SOT-89-3
U6: CD4043BPWR; TSSOP-16_4.4x5mm_P0.65mm
U7: CD4093BPWR; TSSOP-14_4.4x5mm_P0.65mm
U8: XJNG2103; SOIC-8_3.9x4.9mm_P1.27mm
U9, U10, U11, U12: LM317K-TA3-T; TO-220-3_Vertical
U13, U15: ADS1115IDGS; TSSOP-10_3x3mm_P0.5mm
U14: ACS710KLATR-12CB-T; SOIC-16W_7.5x10.3mm_P1.27mm

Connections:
1W: J3.4, U1.1, U2.1, U3.1
/pv2rGateDrv/FET_GATE: D8.1, Q1.1, R9.2, R11.1
/pv2rGateDrv/START_ARMED: TP3.1, U6.1, U7.12
/pv2rGateDrv/__DRV_OUT: TP4.1, U7.3, U7.5, U7.6, U7.13
FET_EN: J3.11, R7.1, U7.8
FET_START: J3.9, U6.14
FET_STATUS: J3.13, R5.1, U7.4
GATE_DRV_IN: R8.2, R10.1, U7.10, U8.3
GATE_DRV_OUT: R4.1, R9.1, U8.5
GATE_DRV_VCC: C2.1, C3.1, C7.1, D11.1, R8.1, U4.1, U5.2, U8.1
GATE_LOGIC_VCC: C4.1, C5.1, C6.1, U5.3, U6.5, U6.16, U7.14
GND: C1.2, C2.2, C3.2, C4.2, C5.2, C6.2, C7.2, C8.2, C9.2, C10.2, C11.2, C12.2, C13.2, C14.2, C15.2, D10.2, D11.2, D16.2, D17.2, J2.1, J3.1, J3.12, J3.14, JP1.2, K1.12, Q2.2, Q3.2, R2.2, R3.2, R6.2, R7.2, R10.2, R11.2, R15.2, R20.2, R21.2, R22.2, R23.2, R26.1, TP1.1, TP2.1, U1.4, U2.4, U3.4, U4.2, U5.1, U6.3, U6.4, U6.6, U6.7, U6.8, U6.11, U6.12, U7.7, U8.2, U8.4, U8.6, U8.7, U8.8, U13.1, U13.3, U13.4, U13.6, U13.7, U14.9, U14.16, U15.3, U15.6, U15.7
LOGIC2: J2.2, J3.15
LOGIC3: J2.3, J3.17
LOGIC4: J2.4, J3.19
LOGIC5: J2.5, J3.20
LOGIC6: J2.6, J3.18
unnamed: C11.1, R25.1, R26.2, TP5.1, U13.5
unnamed: C14.1, U14.11
unnamed: C15.1, TP7.1, U14.10, U15.5
unnamed: D5.3, K1.A1, Q2.3
unnamed: D6.3, K1.A2, Q3.3
unnamed: D10.1, R4.2, R6.1, U7.1, U7.2
unnamed: D12.2, Q5.1, R12.2, R13.1
unnamed: D13.2, Q4.1, Q5.3, R14.1
unnamed: D17.1, R13.2
unnamed: D18.2, D19.1, R16.1, U9.2, U10.3
unnamed: D19.2, D20.1, R17.1, U10.2, U11.3
unnamed: D20.2, D21.1, R18.1, U11.2, U12.3
unnamed: K1.11, R1.2
unnamed: R5.2, U6.15
unnamed: R14.2, R15.1
unnamed: R16.2, R20.1, U9.1
unnamed: R17.2, R21.1, U10.1
unnamed: R18.2, R22.1, U11.1
unnamed: R19.2, R23.1, U12.1
unnamed: R24.1, R25.2
unnamed: TP6.1, U14.12, U15.4
unnamed: U7.9, U7.11
PWR_OUT+: D3.1, J1.1, U14.1, U14.2, U14.3, U14.4
PWR_OUT-: D3.2, D9.1, J1.6, Q1.2
R_RESET: J3.5, Q2.1, R2.1
R_SET: J3.3, Q3.1, R3.1
R_STATUS: J3.7, R1.1
S1+: D1.2, D2.1, D2.3, F2.2, J1.4, K1.21
S1+Fused: D15.2, F2.1, J3.16
S1-: D4.2, D7.1, D7.3, D8.2, D9.2, J1.5, JP1.1, Q1.3
S2+: D1.1, D2.2, F1.2, J1.2, U14.5, U14.6, U14.7, U14.8
S2+Fused: D12.1, D13.1, F1.1, Q4.2, Q5.2, R12.1, R24.2
S2+_IfLow: D14.2, Q4.3
S2-: D4.1, D7.2, J1.3, K1.24
S+: C8.1, D14.1, D15.1, D16.1, D18.1, U9.3
SCL: J3.8, R27.1, U13.10, U15.10
SDA: J3.6, R28.1, U13.9, U15.9
V24: C1.1, C9.1, D5.2, D6.2, D21.2, J3.2, K1.A3, R19.1, U4.3, U12.2
V33P: C10.1, C12.1, C13.1, J3.10, K1.14, R27.2, R28.2, U1.8, U2.8, U3.8, U13.8, U14.14, U14.15, U15.1, U15.8

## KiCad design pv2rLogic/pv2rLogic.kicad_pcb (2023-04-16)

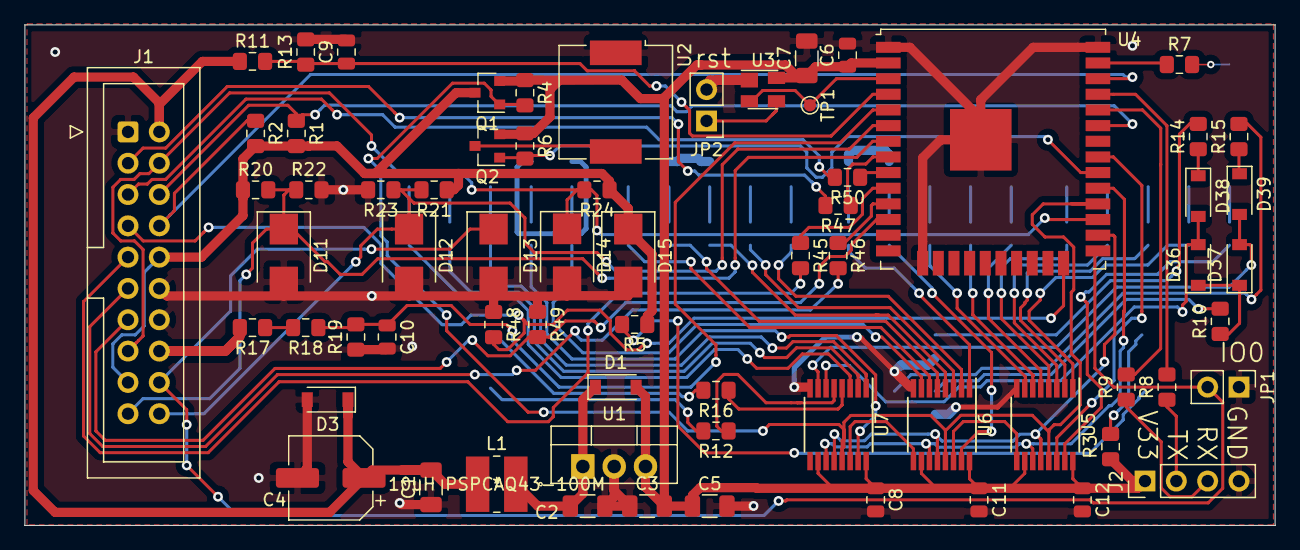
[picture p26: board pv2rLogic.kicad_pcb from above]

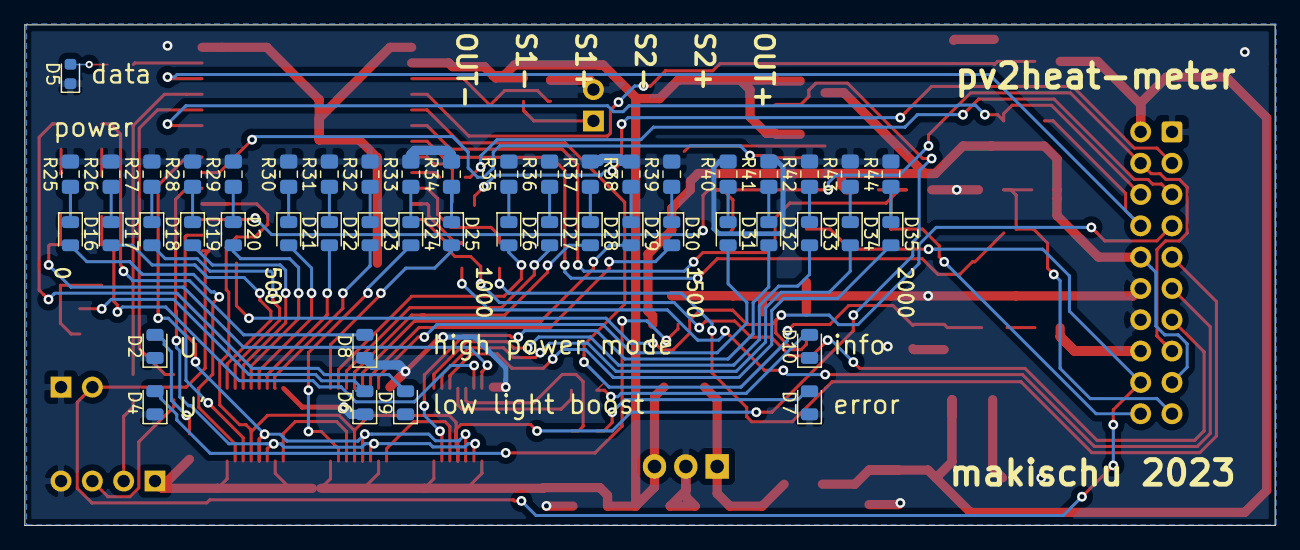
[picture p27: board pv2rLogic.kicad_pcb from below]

Board: 2 copper layers, 101.4 x 40.6 mm, 116 parts (48 on the bottom side), 95 nets.

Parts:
C1, C2, C3: 10uF CL31A106KBHNNNE; C_1206_3216Metric
C4: DNP; CP_Elec_6.3x7.7
C5: DNP; C_1206_3216Metric
C6, C8, C9, C10, C11, C12: 0.1uF CC0805KRX7R9BB104; C_0805_2012Metric
C7: 10uF tantal TAJA106K016RNJ; C_1206_3216Metric
D1, D36, D37, D38, D39: 1N4148W; D_SOD-123
D2, D4, D6, D8, D9, D16, D17, D18, D19, D20, D21, D22, D23, D24, D25, D26, D27, D28, D29, D30, D31, D32, D33, D34, D35: LED C2297; LED_0805_2012Metric
D3: BZT52C27; D_SOD-123
D5: LED C72041; LED_0603_1608Metric
D7: LED RD C84256; LED_0805_2012Metric
D10: LED YE C2296; LED_0805_2012Metric
D11, D12, D13, D14, D15: SMLVT3V3; D_SMB
J1: C3405; IDC-Header_2x10_P2.54mm_Vertical
J2: UART; PinHeader_1x04_P2.54mm_Vertical
JP1, JP2: Jumper; PinHeader_1x02_P2.54mm_Vertical
L1: 10uH PSPCAQ43-100M; PSPCAQ43-100M
Q1, Q2: AO3401A; SOT-23
R1, R2, R24: 4.7K; R_0805_2012Metric_Pad1.15x1.40mm_HandSolder
R3, R5, R25, R26, R27, R28, R29, R30, R31, R32, R33, R34, R35, R36, R37, R38, R39, R40, R41, R42, R43, R44: 1K; R_0805_2012Metric_Pad1.15x1.40mm_HandSolder
R4, R6, R48, R49: 100K; R_0805_2012Metric_Pad1.15x1.40mm_HandSolder
R7: 120; R_0805_2012Metric_Pad1.15x1.40mm_HandSolder
R8, R9: 100; R_0805_2012Metric_Pad1.15x1.40mm_HandSolder
R10, R14, R15: 470; R_0805_2012Metric_Pad1.15x1.40mm_HandSolder
R11: 470K; R_0805_2012Metric_Pad1.15x1.40mm_HandSolder
R12, R16, R45, R46, R47, R50: 220; R_0805_2012Metric_Pad1.15x1.40mm_HandSolder
R13, R22, R23: 10K; R_0805_2012Metric_Pad1.15x1.40mm_HandSolder
R17, R18: 1Meg; R_0805_2012Metric_Pad1.15x1.40mm_HandSolder
R19: 13.3k TR0805C13K3P0515; R_0805_2012Metric_Pad1.15x1.40mm_HandSolder
R20, R21: 24K; R_0805_2012Metric_Pad1.15x1.40mm_HandSolder
TP1: EN; TestPoint_Pad_D1.0mm
U1: LCB78_03-0.5; TO-220-3_Vertical
U2: GSD128065YB-3V2400; Buzzer_GSD128065YB
U3: MAX811SEUS-T; SOT-143
U4: ESP32-WROOM-32UE-N8; ESP32-WROOM-32U
U5, U6, U7: SN74HC595PWR; TSSOP-16_4.4x5mm_P0.65mm

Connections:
1W: D14.1, J1.4, J1.15, R24.2, U4.27
DIGIN1: D11.1, J1.19, R20.2, R22.1, U4.7
DIGIN2: D12.1, J1.20, R21.2, R23.1, U4.6
DIGIN3: D13.1, J1.18, JP1.2, U4.25
EN: TP1.1, U3.2, U4.3
FET_EN: J1.11, R46.2
FET_START: J1.9, R45.2
FET_STATUS: J1.13, R49.2, U4.12
GND: C1.1, C2.1, C3.1, C4.2, C5.2, C6.2, C7.2, C8.2, C9.2, C10.2, C11.2, C12.2, D2.1, D3.2, D4.1, D5.1, D6.1, D7.1, D8.1, D9.1, D10.1, D11.2, D12.2, D13.2, D14.2, D15.2, J1.1, J1.12, J1.14, J2.4, JP1.1, JP2.2, R13.2, R19.1, R22.2, R23.2, R25.2, R26.2, R27.2, R28.2, R29.2, R30.2, R31.2, R32.2, R33.2, R34.2, R35.2, R36.2, R37.2, R38.2, R39.2, R40.2, R41.2, R42.2, R43.2, R44.2, R48.1, R49.1, U1.2, U2.1, U3.1, U4.1, U4.15, U4.38, U4.39, U5.8, U6.8, U7.8
IO2: J1.7, R48.2, U4.24
IO4: U4.26, U5.12, U6.12, U7.12
IO5: U4.29, U5.11, U6.11, U7.11
IO18: Q2.1, R6.2, U4.30
IO19: U4.31, U5.14
IO23: R7.1, U4.37
IO25: R45.1, U4.10
IO26: R46.1, U4.11
IO32: R47.1, U4.8
IO33: R50.1, U4.9
IO_PER_EN: Q1.1, R4.2, U4.28, U5.13, U6.13, U7.13
LEDO1: D16.2, U5.15
LEDO2: D17.2, U5.1
LEDO3: D18.2, U5.2
LEDO4: D19.2, U5.3
LEDO5: D20.2, U5.4
LEDO6: D21.2, U5.5
LEDO7: D22.2, U5.6
LEDO8: D23.2, U5.7
LEDO9: D24.2, U6.15
LEDOA: D25.2, U6.1
LEDOB: D26.2, U6.2
LEDOC: D27.2, U6.3
LEDOD: D28.2, U6.4
LEDOE: D29.2, U6.5
LEDOF: D30.2, U6.6
LEDOG: D31.2, U6.7
LEDOH: D32.2, U7.15
LEDOI: D33.2, U7.1
LEDOJ: D34.2, U7.2
LEDOK: D35.2, U7.3
LEDOW: R16.1, U7.4
LEDOX: R12.1, U7.5
LEDOY: D36.2, D38.2, U7.6
LEDOZ: D37.2, D39.2, U7.7
LOGIC3: D15.1, J1.10, J1.17, Q1.3, R1.2, R2.2, R5.1, R20.1, R21.1, R24.1
unnamed: C2.2, D1.1, L1.1, U1.1
unnamed: C9.1, R11.2, R13.1, U4.4
unnamed: C10.1, R18.1, R19.2, U4.5
unnamed: D2.2, R3.2
unnamed: D4.2, R5.2
unnamed: D5.2, R7.2
unnamed: D6.2, R10.2
unnamed: D7.2, R12.2
unnamed: D8.2, R14.2
unnamed: D9.2, R15.2
unnamed: D10.2, R16.2
unnamed: D16.1, R25.1
unnamed: D17.1, R26.1
unnamed: D18.1, R27.1
unnamed: D19.1, R28.1
unnamed: D20.1, R29.1
unnamed: D21.1, R30.1
unnamed: D22.1, R31.1
unnamed: D23.1, R32.1
unnamed: D24.1, R33.1
unnamed: D25.1, R34.1
unnamed: D26.1, R35.1
unnamed: D27.1, R36.1
unnamed: D28.1, R37.1
unnamed: D29.1, R38.1
unnamed: D30.1, R39.1
unnamed: D31.1, R40.1
unnamed: D32.1, R41.1
unnamed: D33.1, R42.1
unnamed: D34.1, R43.1
unnamed: D35.1, R44.1
unnamed: D36.1, D37.1, R10.1
unnamed: D38.1, R14.1
unnamed: D39.1, R15.1
unnamed: J2.2, R8.1
unnamed: J2.3, R9.1
unnamed: JP2.1, U3.3
unnamed: Q2.3, U2.2
unnamed: R8.2, U4.35
unnamed: R9.2, U4.34
unnamed: R17.1, R18.2
unnamed: U5.9, U6.14
unnamed: U6.9, U7.14
R_RESET: J1.5, R50.2
R_SET: J1.3, R47.2
S1+Fused: J1.16, R17.2
SCL: J1.8, R2.1, U4.36
SDA: J1.6, R1.1, U4.33
V24: C1.2, C4.1, D3.1, J1.2, L1.2, R11.1
V33: C3.2, C5.1, C6.1, C7.1, C8.1, C11.1, C12.1, D1.2, J2.1, Q1.2, Q2.2, R3.1, R4.1, R6.1, U1.3, U3.4, U4.2, U5.10, U5.16, U6.10, U6.16, U7.10, U7.16

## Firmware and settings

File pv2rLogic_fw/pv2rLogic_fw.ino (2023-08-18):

//27.01.23 makischu as-is
//Version 04: for Hardware V04 - changed voltage supply and logic signals. includes uvlo latch and measurements.
//part of direct-pv2heat-meter. bridge between hardware (PCBs) and bluetooth low energy (BLE).
// sends out status (voltage, current, ...) every second
// can receive a few commands (turing power output off/on, ...).
// and switches between two wiring states automatically to maximize power output.
//
//makes use of esp32 board support for arduino and some arduino librarys: 
// Temperature-Sens:  https://github.com/milesburton/Arduino-Temperature-Control-Library
//and is partly based on the following code examples:
// Timer:             https://github.com/espressif/arduino-esp32/blob/master/libraries/ESP32/examples/Timer/RepeatTimer/RepeatTimer.ino
// BLE:               https://github.com/nkolban/ESP32_BLE_Arduino/blob/master/examples/BLE_notify/BLE_notify.ino
// Shift register:    https://docs.arduino.cc/tutorials/communication/guide-to-shift-out#shftout11
// Firmwareupdate:    https://github.com/espressif/arduino-esp32/blob/master/libraries/ArduinoOTA/examples/OTAWebUpdater/OTAWebUpdater.ino
// ...


// PIN wiring
#define __PER_EN      (17)
#define __BUZZER      (18) // not placed.
#define LED_DATA      (23)
#define DIGIN1        (35)
#define DIGIN2        (34)
#define DIGIN3         (0)  
#define FET_STATUS    (27)
#define R_STATUS       (2)
#define FET_START     (25)
#define FET_EN        (26)
#define R_SET         (32)
#define R_RESET       (33)
#define ONE_WIRE_BUS  (16)
#define ANALOG_PIN24  (36)
#define ANALOG_PINS1  (39)

// output may only be enabled when ALL conditions are met.
#define OK_REQUEST    (0x01) //request must exist (hardwired / BLE / ext. temp sensor (the latter not implemented yet))
#define OK_RES_MON    (0x02) //load resistance has to be a senseful value
#define OK_TEMP_MON   (0x04) //internal temperature must not be too high
#define OK_NO_REBOOT  (0x08) //stop power when reboot requested
#define OK_HW         (0x20) //no hardware error must be known.

#define OK_ALL (OK_REQUEST|OK_RES_MON|OK_TEMP_MON|OK_NO_REBOOT|OK_HW)

//errors are assumed to be permanent hardware failures (maybe fixed with next restart/repowering)
#define ERR_ADC       (0x01)
#define ERR_1W        (0x02)
#define ERR_BADFET    (0x04)

//status bits (for output via BLE)
#define STA_RELAIS_SET            (0x01)
#define STA_FET_ON                (0x02)
#define STA_INFO                  (0x04)
#define STA_ERROR                 (0x08)
#define STA_DIGIN1                (0x10)
#define STA_DIGIN2                (0x20)
#define STA_DIGIN3                (0x40)
#define STA_DIGIN1_NOT            (0x80)
#define STA_RELAIS_SET_FORCED    (0x100)
#define STA_RELAIS_RESET_FORCED  (0x200)
#define STA_FAST_OFF_ACTION      (0x400)
//higher bits are used for temporary things


// each time step consists of 3 steps:
// 1. read inputs, from hardware and BLE.
// 2. interpret&act, incl. power output handling (the most interesting part).
// 3. generate and write (logic) outputs (LEDs and BLE).

// variables read from hardware
struct Inputs {
  float     UoutV;
  float     IoutA;
  uint16_t  U24mV;
  uint16_t  US1cV;
  int16_t   TempIntcC;
  int16_t   TempExtcC;
  int       DigIn1;
  int       DigIn2;
  int       DigIn3;
  int       RelaisStatus; //0 reset, 1 set.
  int       FetStatus; //0 off, 1 on.
  uint8_t   BleCmd[4];
};

// states which are calculated/stored internally, including power logic.
struct Internals {
  float     Inoload;
  float     Rload;
  uint32_t  t_Rload_set;
  float     PwrOutW;
  int       Errors;       //ERR_*
  int       PwrOutOk;     //OK_*
  uint8_t 	LastReceivedCmdNr;
  uint32_t  PowerOutOn_BT;
  uint32_t  t_PowerOutOn_BT;
  uint32_t  t_LastRelaisAction;
  int       relaisActionCount;
  int       RelaisMode;   // 5 set, 8 reset, other: automatic (->StateOut).
  uint16_t  U24mV_atLastRelaisCmd;  
  int       relaisActionCount_lastReported;
  int       fastAction;
  int       OTARequested;
  int       ResetRequested;
};

// outputs to be displayed and/or sent.
struct __attribute__((packed)) Outputs {
  uint16_t  Status;    //STA_...bits
  uint16_t  TempIntcC;
  uint16_t  TempExtcC;
  uint16_t  UoutcV;
  int16_t  IoutmA;
  uint16_t  U24mV;  // U24mV_atLastRelaisCmd at change of LastReceivedCmdNr
  uint16_t  US1cV;
  uint16_t  __free__was_PwrAlttW;
  uint16_t  __free__was_a_inv_em9; //inverted, times e+9.
  uint8_t   __free__was_b_di2_em3; //divided/2, times e+3.
  uint8_t   LastReceivedCmdNr;
}; //max 20bytes.

Inputs    input;
Internals intern;
Outputs   output;



// Math (see theory). 
// simplified and only valid for my configuration of source and load
inline void getSwitchingPointsP(float* pPtoSet, float* pPtoReset, float T_C) {
  const float cSp_par = -2.045406502f;
  const float Sp0_par = 326.6950852f;
  const float cSp_ser = -2.44131286f;
  const float Sp0_ser = 400.671502f;
  float PtoSer = Sp0_ser + cSp_ser*T_C - 5.0f;
  float PtoPar = Sp0_par + cSp_par*T_C;
  if(pPtoSet)   *pPtoSet = PtoSer;
  if(pPtoReset) *pPtoReset = PtoPar;
}
// simplified and only valid for my configuration of source and load
inline void getSwitchingPointsU(float* pUtoSet, float* pUtoReset, float T_C) {
  const float cSp_par = -0.36754060106676795f;
  const float Sp0_par = 107.56084823287758f;
  const float cSp_ser = -0.39504819148813525f;
  const float Sp0_ser = 119.10965758956989f;
  float UtoSer = Sp0_ser + cSp_ser*T_C;
  float UtoPar = Sp0_par + cSp_par*T_C;
  if(pUtoSet)   *pUtoSet = UtoSer;
  if(pUtoReset) *pUtoReset = UtoPar;
}


/////////////////////////////////////
#include <WiFi.h>
#include <WiFiClient.h>
#include <WebServer.h>
#include <ESPmDNS.h>
#include <Update.h>
const char* host = "esp32meter";
const char* ssid = "yourSSID";
const char* password = "yourPW";
WebServer server(80);
int OTAMode=0;
/*
 * Login page
 */
const char* loginIndex =
 "<form name='loginForm'>"
    "<table width='20%' bgcolor='A09F9F' align='center'>"
        "<tr>"
            "<td colspan=2>"
                "<center><font size=4><b>ESP32meter Login Page</b></font></center>"
                "<br>"
            "</td>"
            "<br>"
            "<br>"
        "</tr>"
        "<tr>"
             "<td>Username:</td>"
             "<td><input type='text' size=25 name='userid'><br></td>"
        "</tr>"
        "<br>"
        "<br>"
        "<tr>"
            "<td>Password:</td>"
            "<td><input type='Password' size=25 name='pwd'><br></td>"
            "<br>"
            "<br>"
        "</tr>"
        "<tr>"
            "<td><input type='submit' onclick='check(this.form)' value='Login'></td>"
        "</tr>"
    "</table>"
"</form>"
"<script>"
    "function check(form)"
    "{"
    "if(form.userid.value=='admin' && form.pwd.value=='admin')"
    "{"
    "window.open('/serverIndex')"
    "}"
    "else"
    "{"
    " alert('Error Password or Username')/*displays error message*/"
    "}"
    "}"
"</script>";

const char* htmlReboot =
 "rebooting";
/*
 * Server Index Page
 */
const char* serverIndex =
"<script src='https://ajax.googleapis.com/ajax/libs/jquery/3.2.1/jquery.min.js'></script>"
"<form method='POST' action='#' enctype='multipart/form-data' id='upload_form'>"
   "<input type='file' name='update'>"
        "<input type='submit' value='Update'>"
    "</form>"
 "<div id='prg'>progress: 0%</div>"
 "<script>"
  "$('form').submit(function(e){"
  "e.preventDefault();"
  "var form = $('#upload_form')[0];"
  "var data = new FormData(form);"
  " $.ajax({"
  "url: '/update',"
  "type: 'POST',"
  "data: data,"
  "contentType: false,"
  "processData:false,"
  "xhr: function() {"
  "var xhr = new window.XMLHttpRequest();"
  "xhr.upload.addEventListener('progress', function(evt) {"
  "if (evt.lengthComputable) {"
  "var per = evt.loaded / evt.total;"
  "$('#prg').html('progress: ' + Math.round(per*100) + '%');"
  "}"
  "}, false);"
  "return xhr;"
  "},"
  "success:function(d, s) {"
  "console.log('success!')"
 "},"
 "error: function (a, b, c) {"
 "}"
 "});"
 "});"
 "</script>";


/***************************************************************************
* Example sketch for the ADS1115_WE library
*
* This sketch shows how to use the ADS1115 in single shot mode. 
*  
* Further information can be found on:
* https://wolles-elektronikkiste.de/ads1115 (German)
* https://wolles-elektronikkiste.de/en/ads1115-a-d-converter-with-amplifier (English)
* 
***************************************************************************/

#include<ADS1115_WE.h> 
#include<Wire.h>
#define I2C_ADDRESS1 0x48
#define I2C_ADDRESS2 0x49

/* There are several ways to create your ADS1115_WE object:
 * ADS1115_WE adc = ADS1115_WE(); -> uses Wire / I2C Address = 0x48
 * ADS1115_WE adc = ADS1115_WE(I2C_ADDRESS); -> uses Wire / I2C_ADDRESS
 * ADS1115_WE adc = ADS1115_WE(&Wire); -> you can pass any TwoWire object / I2C Address = 0x48
 * ADS1115_WE adc = ADS1115_WE(&Wire, I2C_ADDRESS); -> all together
 */
ADS1115_WE adc1 = ADS1115_WE(I2C_ADDRESS1);
ADS1115_WE adc2 = ADS1115_WE(I2C_ADDRESS2);

//read current through U1/ACS710/output
float readCurrent() {
  float voltage = 0.0;
  float current = 0.0;
  voltage = adc2.getResult_mV(); 
  current = -1.0*voltage/56.0*5.0/3.3;

  // print out the values you read:
  //Serial.printf("current out analog value = %f\n",voltage);
  //Serial.printf("Iout[V] = %f\n",current);

  return current;
}

//use the current current value as 0
void zeroCurrent() {
  float f=0;
  const int n = 10;
  //adc2.setConvRate(ADS1115_32_SPS);

  //self-calibration of zero current value
  delay(90); // let analog filter settle.
  f=0;
  for(int i=0;i<n;i++) { // some averaging is appropriate in case of noise
    delay(10); // samplerate 1/128 => 10ms should be sufficient to gain new value
    f += readCurrent(); 
  }
  f/=n;
  if (abs(f) < 1.0f) {
    intern.Inoload = f; 
  } else {
    Serial.print("inplausible no load current");
    intern.Errors |= ERR_BADFET;
  }
  
  //adc2.setConvRate(ADS1115_128_SPS);
}

float readCurrentCorrected() {
  float current = readCurrent();
  current -= intern.Inoload;
  return current;
}

//read voltage over output (before fets)
float readVoltageOut() {
  float voltage = 0.0;
  float strvolt = 0.0;
  voltage = adc1.getResult_mV(); 
  strvolt = -1.0*voltage/6.8*2006.8/1000.0;

  // print out the values you read:
  //Serial.printf("voltage out analog value = %f\n",voltage);
  //Serial.printf("Vout[V] = %f\n",strvolt);

  return strvolt;
}

//read voltage on 24V rail in mV
uint16_t readVoltage24mV() {
  //int analogValue24 = analogRead(ANALOG_PIN24);
  int analogVolts24 = analogReadMilliVolts(ANALOG_PIN24);
  int volts24 = analogVolts24 * ((470+10)/(10));
  
  // print out the values you read:
  // Serial.printf("24 ADC analog value = %d\n",analogValue24);
  // Serial.printf("24 ADC millivolts value = %d\n",analogVolts24);
  //Serial.printf("V24[mV] = %d\n",volts24);
  return (uint16_t)volts24;
}

//read voltage over S1 in cV
uint16_t readVoltageS1cV() {
  //int analogValueS1 = analogRead(ANALOG_PINS1);
  int analogVoltsS1 = analogReadMilliVolts(ANALOG_PINS1);
  int voltsS1 = analogVoltsS1 * ((20000+133)/(133));
  
  // print out the values you read:
  //Serial.printf("S1 ADC analog value = %d\n",analogValueS1);
  // Serial.printf("S1 ADC millivolts value = %d\n",analogVoltsS1);
  //Serial.printf("VS1[mV] = %d\n",voltsS1);
  return (uint16_t)(voltsS1/10);
}

//read DIGIN, by ADC to distinguish n.c.(-1), 0 and 1.
int readDigIn1() {
  int analogMilliVolts = analogReadMilliVolts(DIGIN1);
  int result = analogMilliVolts < 500 ? 0 : analogMilliVolts > 2000 ? 1 : -1;
  return result;
}
//read DIGIN, by ADC to distinguish n.c.(-1), 0 and 1.
int readDigIn2() {
  //int analogValue = analogRead(DIGIN2);
  int analogMilliVolts = analogReadMilliVolts(DIGIN2);
  int result = analogMilliVolts < 500 ? 0 : analogMilliVolts > 2000 ? 1 : -1;
  //Serial.printf("DigIn2 ADC analog value = %d\n",analogValue);
  //Serial.printf("DigIn2 ADC millivolts value = %d\n",analogMilliVolts);
  return result;
}



//**************************************************************//
//  Name    : shiftOutCode, Hello World
//  Author  : Carlyn Maw,Tom Igoe, David A. Mellis
//  Date    : 25 Oct, 2006
//  Modified: 23 Mar 2010
//  Version : 2.0
//  Notes   : Code for using a 74HC595 Shift Register           //
//          : to count from 0 to 255
//****************************************************************
//Pin connected to ST_CP of 74HC595
const int latchPin = 4;
//Pin connected to SH_CP of 74HC595
const int clockPin = 5;
//Pin connected to DS of 74HC595
const int dataPin = 19;


//https://randomnerdtutorials.com/esp32-save-data-permanently-preferences/
#include <Preferences.h>
Preferences preferences;
#define PREF_NS "esp32meter"
#define PREF_1WINT "1Wint"
#define PREF_OTARQ "OTARq"


/*
    Video: https://www.youtube.com/watch?v=oCMOYS71NIU
    Based on Neil Kolban example for IDF: https://github.com/nkolban/esp32-snippets/blob/master/cpp_utils/tests/BLE%20Tests/SampleNotify.cpp
    Ported to Arduino ESP32 by Evandro Copercini
    updated by chegewara

   Create a BLE server that, once we receive a connection, will send periodic notifications.
   The service advertises itself as: 4fafc201-1fb5-459e-8fcc-c5c9c331914b
   And has a characteristic of: beb5483e-36e1-4688-b7f5-ea07361b26a8

   The design of creating the BLE server is:
   1. Create a BLE Server
   2. Create a BLE Service
   3. Create a BLE Characteristic on the Service
   4. Create a BLE Descriptor on the characteristic
   5. Start the service.
   6. Start advertising.

   A connect hander associated with the server starts a background task that performs notification
   every couple of seconds.
*/
#include <BLEDevice.h>
#include <BLEServer.h>
#include <BLEUtils.h>
#include <BLE2902.h>


// Include the libraries we need for 1Wire
#include <OneWire.h>
#include <DallasTemperature.h>

// Setup a oneWire instance to communicate with any OneWire devices (not just Maxim/Dallas temperature ICs)
OneWire oneWire(ONE_WIRE_BUS);

// Pass our oneWire reference to Dallas Temperature. 
DallasTemperature sensors(&oneWire);

//address of the internal temperature sensor. to distinguish from external on same bus.
uint8_t internalTempAddress[8];
uint8_t internalTempAddressOld[8];





/*
 Repeat timer example

 This example shows how to use hardware timer in ESP32. The timer calls onTimer
 function every second. The timer can be stopped with button attached to PIN 0
 (IO0).

 This example code is in the public domain.
 */
hw_timer_t * timer = NULL;
volatile SemaphoreHandle_t timerSemaphore;
portMUX_TYPE timerMux = portMUX_INITIALIZER_UNLOCKED;

volatile uint32_t isrCounter = 0;
volatile uint32_t lastIsrAt = 0;

void IRAM_ATTR onTimer(){
  // Increment the counter and set the time of ISR
  portENTER_CRITICAL_ISR(&timerMux);
  isrCounter++;
  lastIsrAt = millis();
  portEXIT_CRITICAL_ISR(&timerMux);
  // Give a semaphore that we can check in the loop
  xSemaphoreGiveFromISR(timerSemaphore, NULL);
  // It is safe to use digitalRead/Write here if you want to toggle an output
}


BLEServer* pServer = NULL;
BLECharacteristic* pCharacteristicStatus = NULL;
BLECharacteristic* pCharacteristicCmd = NULL;
bool deviceConnected = false;
bool oldDeviceConnected = false;

// See the following for generating UUIDs:
// https://www.uuidgenerator.net/
#define SERVICE_UUID                "58fad6cc-53b4-4dfd-ad3f-2072af1bbf2c"
#define CHARACTERISTIC_STATUS_UUID  "2a201432-a3c9-4b7c-b3ed-24b72d7f9158"
#define CHARACTERISTIC_CMD_UUID     "cf1ac9a7-87fe-400a-9bcf-a296dbc868c4"


class MyServerCallbacks: public BLEServerCallbacks {
    void onConnect(BLEServer* pServer) {
      deviceConnected = true;
    };

    void onDisconnect(BLEServer* pServer) {
      deviceConnected = false;
    }
};


//Illuminat status LEDs ("Outgoing User Interface"), except data LED.
void setRegisterLeds(int powerIndex, bool info, bool error, bool parallel, bool serial) 
{
  int byte1=0;
  int byte2=0;
  int byte3=0;
  if (powerIndex>=0 && powerIndex<=7) {
    byte1 |= 1<<(powerIndex);
  }
  if (powerIndex>=8 && powerIndex<=15) {
    byte2 |= 1<<(powerIndex-8);
  }
  if (powerIndex>=16 && powerIndex<=19) {
    byte3 |= 1<<(powerIndex-16);
  }
  if (info) {
    byte3 |= 0x10;
  }
  if (error) {
    byte3 |= 0x20;
  }
  if (parallel) {
    byte3 |= 0x80;
  }
  if (serial) {
    byte3 |= 0x40;
  }

  digitalWrite(latchPin, LOW);
  shiftOut(dataPin, clockPin, MSBFIRST, byte3);
  shiftOut(dataPin, clockPin, MSBFIRST, byte2);
  shiftOut(dataPin, clockPin, MSBFIRST, byte1);
  digitalWrite(latchPin, HIGH);
}

//unfortunately a function like this is missing in the library... other people seem to prefer float.
// returns temperature in 1/128 degrees C or DEVICE_DISCONNECTED_RAW if the
// device's scratch pad cannot be read successfully.
int32_t sensors_getTempRawByIndex(uint8_t deviceIndex) {
  DeviceAddress deviceAddress;
  if (!sensors.getAddress(deviceAddress, deviceIndex)) {
    return DEVICE_DISCONNECTED_RAW;
  }
  return sensors.getTemp((uint8_t*) deviceAddress);
}
//convert to 0.01°C, without float.
int16_t sensors_getTempIntcCByIndex(uint8_t deviceIndex) {
  int32_t tempRaw = sensors_getTempRawByIndex(deviceIndex);
  if (tempRaw <= DEVICE_DISCONNECTED_RAW) {
    return 0x8000;
  } else {
    //C = RAW/128 >= cC = RAW*100/128
    return (int16_t)((tempRaw*100)/128);
  }
}

//read internal temperature, in 0.01°C.
int16_t sensors_getTempcCInternal() {
  int32_t tempRaw =  sensors.getTemp(internalTempAddress);
  if (tempRaw <= DEVICE_DISCONNECTED_RAW) {
    return 0x8000;
  } else {
    //C = RAW/128 >= cC = RAW*100/128
    return (int16_t)((tempRaw*100)/128);
  }
}

//read external (not the internal) temperature, if any.
int16_t sensors_getTempcCExternal() {
  uint8_t extIdx=0;
  DeviceAddress deviceAddress;
  if (!sensors.getAddress(deviceAddress, 0)) {
    return DEVICE_DISCONNECTED_RAW;
  }
  if(0==memcmp(deviceAddress,internalTempAddress,8)) {
    //wenn 0 der interne ist dann kann es nicht der externe sein => probiere 1.
    //wenn 0 nicht der interne ist, dann muss es der externe sein.
    extIdx=1;
  }
  return sensors_getTempIntcCByIndex(extIdx);
}



// Activate or deactivate FET.
void setFet(bool doSet) {
  if (doSet) {
    digitalWrite(FET_START, 1);
    delay(1);
    digitalWrite(FET_START, 0);
    delay(1);
  }
  digitalWrite(FET_EN, doSet?1:0);
}

#define ADC_SETTLING_TIME_MS (50+20)
// according to simulation, value decreases to <1% after 50ms, despite low pass filter. 
// consider adc sampling time. todo! solang getriggert ists egal, aber das will ich ja nicht dauerhaft.
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
void loop() {
  uint32_t isrCount = 0, isrTime = 0;
  bool timer100msExpired = false;
  bool timer1000msExpired = false;
  
  //OTA
  if(OTAMode) {
   server.handleClient();
   delay(1);
   return;
  }
  
  // If Timer has fired
  if (xSemaphoreTake(timerSemaphore, 0) == pdTRUE){
    // Read the interrupt count and time
    portENTER_CRITICAL(&timerMux);
    isrCount = isrCounter;
    isrTime = lastIsrAt;
    portEXIT_CRITICAL(&timerMux);
    timer1000msExpired = isrCount%10==0;
    timer100msExpired = !timer1000msExpired;
    // if (timer1000msExpired) {
    //   // Print it
    //   Serial.print("onTimer no. ");
    //   Serial.print(isrCount);
    //   Serial.print(" at ");
    //   Serial.print(isrTime);
    //   Serial.print(" ms / ");
    //   Serial.print(millis());
    //   Serial.println(" ms");
    // }
  }

  if(timer100msExpired) {
    actFast();
  }
  if (timer1000msExpired) {
    //read BLE input
    if (deviceConnected) {
        uint8_t* pRawCmd = pCharacteristicCmd->getData();
        if(pRawCmd) memcpy(input.BleCmd, pRawCmd, 4);
    } else {
       memset(input.BleCmd, 0, 4);
    }

    ////////////////////////////////////////////////////vvvv MAIN LOGIC vvvv
    //Serial.println("_");
    readInputs();
    //Serial.println("__");
    interpretAndAct();
    //Serial.println("___");
    generateOutputs();
    //Serial.println("____");
    ////////////////////////////////////////////////////^^^^ MAIN LOGIC ^^^^

    //Set static leds
    int pwrIdx = ( (int)output.UoutcV * (int)output.IoutmA ) / (100 * 100* 1000);
    pwrIdx = min(pwrIdx, 19);
    if (input.FetStatus==0) pwrIdx = -1;
    setRegisterLeds(pwrIdx, output.Status&STA_INFO, output.Status&STA_ERROR, input.RelaisStatus==0, input.RelaisStatus==1);
   
    // notify changed value on BLE
    if (deviceConnected) {
        pCharacteristicStatus->setValue((uint8_t*)&output, sizeof(output));
        pCharacteristicStatus->notify();
        delay(9); // 99. bluetooth stack will go into congestion, if too many packets are sent, in 6 hours test i was able to go as low as 3ms
    }

    //set dynamic led.
    digitalWrite(LED_DATA, LOW);
    delay(100);
    digitalWrite(LED_DATA, deviceConnected?HIGH:LOW);
  }

  // disconnecting
  if (!deviceConnected && oldDeviceConnected) {
      delay(200); // 500.give the bluetooth stack the chance to get things ready
      pServer->startAdvertising(); // restart advertising
      Serial.println("start advertising");
      oldDeviceConnected = deviceConnected;
  }
  // connecting
  if (deviceConnected && !oldDeviceConnected) {
      // do stuff here on connecting
      oldDeviceConnected = deviceConnected;
  }

  delay(1);
}

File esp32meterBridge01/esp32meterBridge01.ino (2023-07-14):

//03.08.22 makischu as-is
//part of direct-pv2heat-meter. bridge between BLE and Wifi.
// based on https://github.com/espressif/arduino-esp32/blob/master/libraries/AsyncUDP/examples/AsyncUDPServer/AsyncUDPServer.ino
// initially based on https://github.com/nkolban/ESP32_BLE_Arduino/tree/master/examples/BLE_client 
// later rewritten and moved to nimBLE https://github.com/h2zero/NimBLE-Arduino/blob/release/1.4/docs/New_user_guide.md#creating-a-client
// or https://github.com/h2zero/NimBLE-Arduino/blob/release/1.4/examples/NimBLE_Client/NimBLE_Client.ino
// deployed on a Firebeetle https://www.dfrobot.com/product-1590.html

#include "WiFi.h"
#include "AsyncUDP.h"
#include "NimBLEDevice.h" //#include "BLEDevice.h"
//For Watchdog example see https://iotassistant.io/esp32/enable-hardware-watchdog-timer-esp32-arduino-ide/
#include <esp_task_wdt.h>

#define WDT_TIMEOUT 10

const char * ssid = "****";
const char * password = "****";
IPAddress ip (192, 168, *, 38);
//IPAddress dns(192, 168, *, 1);   
IPAddress gw (192, 168, *, 1);   
IPAddress sub(255, 255, 255, 0);
IPAddress remoteIP;
uint16_t  remotePort;
AsyncUDP udp;
unsigned long previousMillis = 0;
unsigned long interval = 10000;
unsigned long nrWifiConnects = 0;
unsigned long nrBLEConnects = 0;
unsigned long tLastBLENotify=0;




#define LED_PWR       (2)
#define LED_BT        (5)
#define LED_WIFI      (13)


#define SERVICE_UUID                "58fad6cc-53b4-4dfd-ad3f-2072af1bbf2c"
#define CHARACTERISTIC_STATUS_UUID  "2a201432-a3c9-4b7c-b3ed-24b72d7f9158"
#define CHARACTERISTIC_CMD_UUID     "cf1ac9a7-87fe-400a-9bcf-a296dbc868c4"
// The remote service we wish to connect to. & The characteristic of the remote service we are interested in.
static NimBLEUUID    serviceUUID(SERVICE_UUID);
static NimBLEUUID    charUUIDstatus(CHARACTERISTIC_STATUS_UUID);
static NimBLEUUID    charUUIDcmd(CHARACTERISTIC_CMD_UUID);

//static BLEAdvertisedDevice*     pRemoteDevice=0;
static NimBLERemoteCharacteristic* pCharacteristicStatus=0;
static NimBLERemoteCharacteristic* pCharacteristicCmd=0;
static NimBLEClient*               pClient =0;
int BLEwriteFails=0;
long rssi_ble = -127;


uint8_t bleCmd[4];
bool    bleCmdPending=0;

uint8_t bleStatus[32];
size_t  bleStatusLen=0;
bool    bleStatusNew=0;
unsigned long tLastBLEStatusNotify=0;



void sendUDPStatus() {
    uint8_t data[64]; uint8_t* pD = data;
    long rssi_wifi = WiFi.RSSI();
    //long rssi_ble  = pRemoteDevice ? pRemoteDevice->getRSSI() : -127;   returns always the same, maybe from the time of scan.
    //long rssi_ble = pClient ? pClient->getRssi() : -127; // with this line sth stopped working... so tried same in loop.
    rssi_ble = pClient ? pClient->getRssi() : -127; //try again... now called from main loop
    uint32_t mills = millis();
    memcpy(pD,"RCVD",4); pD+=4;
    memcpy(pD,bleStatus,bleStatusLen); pD+=bleStatusLen;
    *(pD++) = (uint8_t)(rssi_wifi&0xFF);
    *(pD++) = (uint8_t)(rssi_ble&0xFF);
    *(pD++) = (uint8_t)(nrWifiConnects&0xFF);
    *(pD++) = (uint8_t)(nrBLEConnects&0xFF);
    memcpy(pD,&mills,4); pD+=4;
    size_t res = udp.writeTo(data, pD-data, remoteIP, remotePort);
    //Serial.print("UDP writeTo returned ");
    //Serial.println(res);
}

static void notifyCallback(
  NimBLERemoteCharacteristic* pBLERemoteCharacteristic,
  uint8_t* pData,
  size_t length,
  bool isNotify) {
    Serial.print("Notify callback for characteristic ");
    Serial.print(pBLERemoteCharacteristic->getUUID().toString().c_str());
    Serial.print(" of data length ");
    Serial.println(length);
//    Serial.print("data: ");
//    Serial.println((char*)pData);

    //preapre data for UDP frame.
    if (remotePort != 0 && length < 32 && !bleStatusNew) {
        tLastBLEStatusNotify = millis();
        memcpy(bleStatus,pData,length);
        bleStatusLen = length;
        bleStatusNew = true;
    }
}



void disconnectBLE() {
  if (pClient) {
    NimBLEDevice::deleteClient(pClient);
    pClient = 0;
    pCharacteristicStatus = 0;
    pCharacteristicCmd = 0;
  }
}

// blocking call. kiss.
void connectBLE() {
  Serial.println("connectBLE start");
  disconnectBLE();

  NimBLEScan *pScan = NimBLEDevice::getScan();
  NimBLEScanResults results = pScan->start(4);
  bool subscribed = false;
  
  for(int i = 0; i < results.getCount(); i++) {
    NimBLEAdvertisedDevice device = results.getDevice(i);
    //Serial.print(device.getAddress().toString().c_str());
    //Serial.println(device.getName().c_str());
    
    if (strcmp("ESP32pv",device.getName().c_str()) == 0) {
    //if (device.isAdvertisingService(serviceUuid)) {
      Serial.println("found ESP32pv");
      pClient = NimBLEDevice::createClient();

      if (pClient->connect(&device)) {
        //Serial.println("connected");
        NimBLERemoteService *pService = pClient->getService(serviceUUID);
        
        if (pService != nullptr) {
            //Serial.println("found service");
            pCharacteristicStatus = pService->getCharacteristic(charUUIDstatus);
            pCharacteristicCmd    = pService->getCharacteristic(charUUIDcmd);
            
            if (pCharacteristicStatus != nullptr) {
              //Serial.println("got charac status");
              // std::string value = pCharacteristic->readValue();
              
              if(pCharacteristicStatus->canNotify()) {
                if(pCharacteristicStatus->subscribe(true, notifyCallback)) {
                  subscribed = true;
                  break;
                }
              }
            }
            if (pCharacteristicCmd != nullptr) {
              //Serial.println("got charac cmd");
            }
        }
      } else {
        Serial.println("but failed to connect");
      // failed to connect
      }
    }
  }
  if (pCharacteristicStatus == 0 || pCharacteristicCmd == 0 || subscribed == false) {
    //Serial.println("but charac is missing.... deleting client.");
    disconnectBLE();
    Serial.println("connectBLE failed");
  }
  if (pClient) {
    Serial.println("connectBLE success");
    nrBLEConnects++;
    BLEwriteFails=0;
  }
}

bool BLEwriteCMD(uint8_t* data) {
  bool wrote = false;
  size_t length = 4;
  Serial.println("BLEwriteCMD");
  if (pCharacteristicCmd) {
    wrote = pCharacteristicCmd->writeValue(data,length, true);
    if (wrote  && BLEwriteFails>0)  BLEwriteFails--;
    if (!wrote && BLEwriteFails<=9) BLEwriteFails++;
  }
  Serial.println(wrote ? "CMD written" : "CMD write failed");
  return wrote;
}

bool BLEwriteFailedTooMuch() {
  return BLEwriteFails >= 5;
}
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

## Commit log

2022-08-05 annotated wiring image
2022-09-25 improved stability, added watchdog and status leds
    [esp32meterBridge01.ino]
2023-04-16 Continued story to working prototype.
    [esp32meter3.kicad_pcb, esp32meter3.sch, pv2r5leds.sch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]
2023-04-16 Continued story to working prototype
2023-07-14 explained and implemented switching algorithm
    and made bridge and translator more robust
2023-08-18 eliminated current measurement from decision logic

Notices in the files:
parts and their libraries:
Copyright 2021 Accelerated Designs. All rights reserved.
